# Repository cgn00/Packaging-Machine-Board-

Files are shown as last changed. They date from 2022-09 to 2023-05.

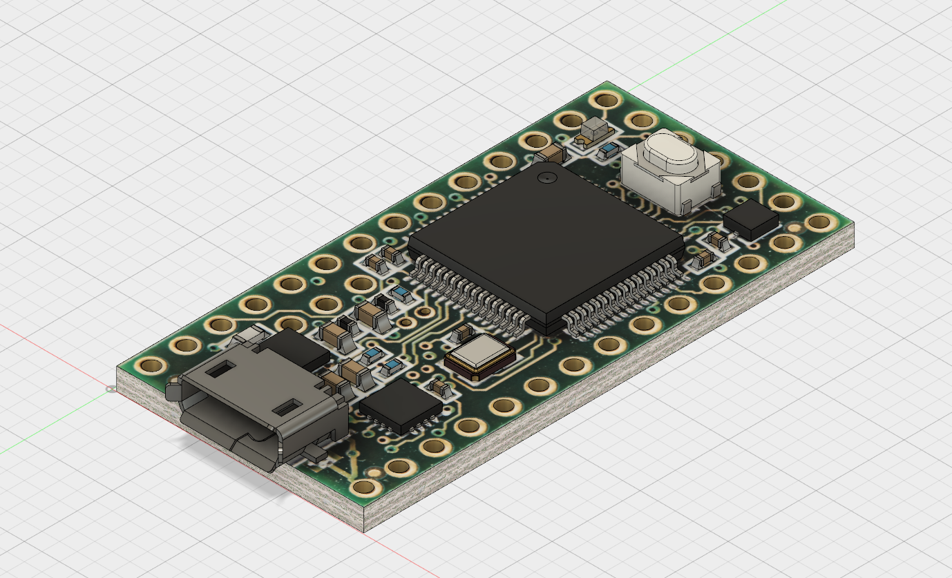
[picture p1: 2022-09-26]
librarys/teensy-3-2-2.snapshot.4/Teensy_3_1 v13.png

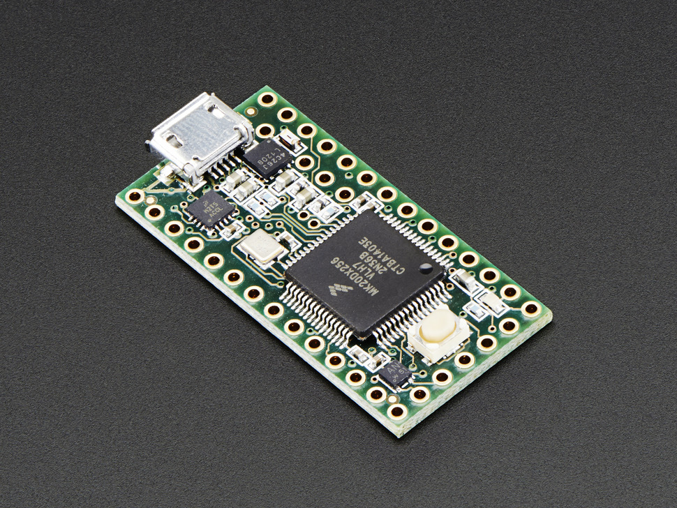
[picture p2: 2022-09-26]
librarys/adafruit-teensy-3-2-header-1.snapshot.2/2756-00.jpg

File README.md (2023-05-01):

# Packaging Machine Controller Board Design

This repository contains the design of a controller board for a packaging machine based on the Teensy 3.5 microcontroller. The controller board allows for control of the motors, sensors, and actuators necessary for the packaging process.

## Installation

To use this controller board, the KiCAD circuit design software is required. Clone this repository and open the .pro file in KiCAD.

## Usage

The controller board is designed to be used in a packaging machine. The pins are labeled and can be easily connected to the corresponding motors, sensors, and actuators.

The firmware necessary for the operation of the packaging machine can be loaded onto the Teensy 3.5 microcontroller using the Arduino development software.

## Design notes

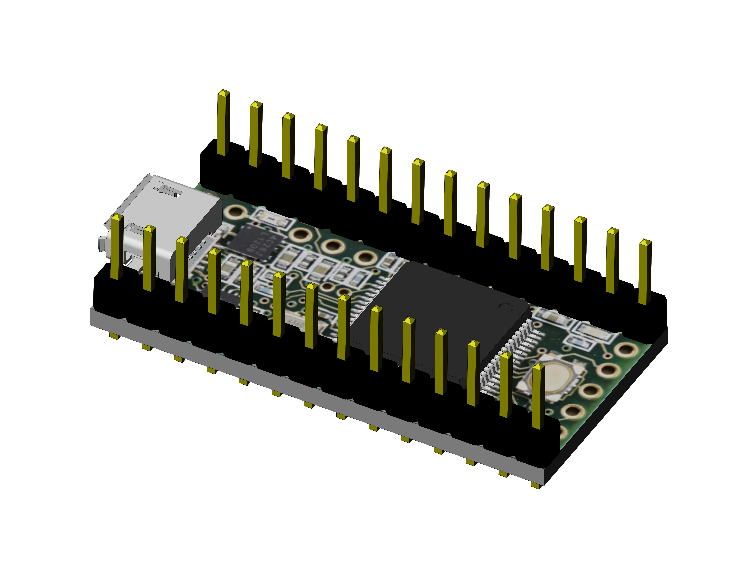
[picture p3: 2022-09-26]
librarys/adafruit-teensy-3-2-header-1.snapshot.2/Teensy 3.2 + header.JPG

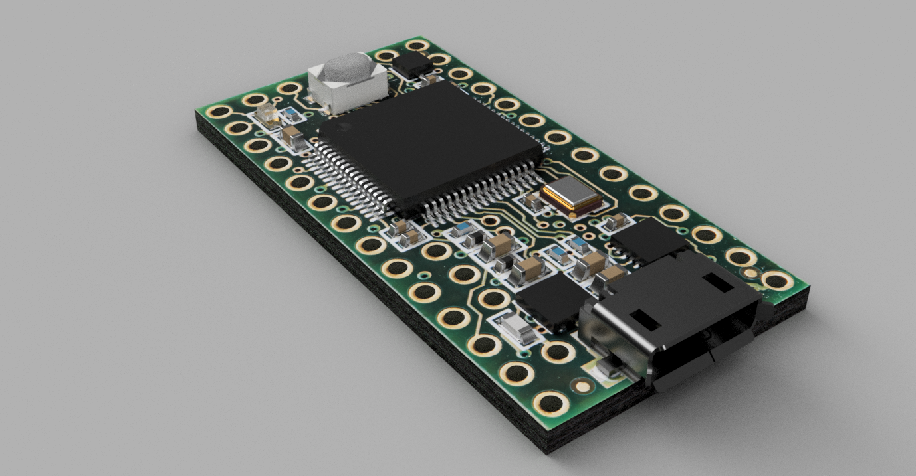
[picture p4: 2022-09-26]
librarys/teensy-3-2-2.snapshot.4/Renderings/Teensy_3_1 v12.png

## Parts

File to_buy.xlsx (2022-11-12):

Reference | Value | Footprint | Dadasheet |  | Qty | Link
BT1 | Battery_Cell | BatteryHolder_Keystone_103_1x20mm_new | ~ |  | 1 | https://lcsc.com/product-detail/Battery-Holders-Clips-Contacts_CR2032battery_C70376.html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
> C1-C14, C23, C24, C26 | 0.1uF | Capacitor_SMD:C_1206_3216Metric | ~ |  | 17 | https://lcsc.com/product-detail/Multilayer-Ceramic-Capacitors-MLCC-SMD-SMT_FH-Guangdong-Fenghua-Advanced-Tech-1206B104K500NT_C110253.html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
C15 | 10uF | Capacitor_SMD:C_0805_2012Metric_Pad1.18x1.45mm_HandSolder | ~ |  | 1 | https://lcsc.com/product-detail/Multilayer-Ceramic-Capacitors-MLCC-SMD-SMT_Murata-Electronics-GRM21BB31A106KE18L_C162316.html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
C16 | 0.1uF | Capacitor_SMD:C_0603_1608Metric_Pad1.08x0.95mm_HandSolder | ~ |  | 1 | https://lcsc.com/product-detail/Multilayer-Ceramic-Capacitors-MLCC-SMD-SMT_CT41G-0603-2X1-50V-0-1mF-K-N_C125205.html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
> C17, C18 | 18pF | Capacitor_SMD:C_0603_1608Metric | ~ |  | 2 | https://lcsc.com/product-detail/Multilayer-Ceramic-Capacitors-MLCC-SMD-SMT_Murata-Electronics-GRM1882C1H180JA01D_C415402.html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
> C19, C20 | 0.1uF | Capacitor_SMD:C_0805_2012Metric_Pad1.18x1.45mm_HandSolder | ~ |  | 2 | https://lcsc.com/product-detail/Multilayer-Ceramic-Capacitors-MLCC-SMD-SMT_CCTC-TCC0805X7R104K500DT_C282732.html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
> C21, C27 | 220uF | Capacitor_SMD:CP_Elec_6.3x7.7 | ~ |  | 2 | https://lcsc.com/product-detail/Aluminum-Electrolytic-Capacitors-Leaded_CX-Dongguan-Chengxing-Elec-220uF-25V-high-frequency_C114911.html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
C22 | 0.1uF | Capacitor_SMD:C_0805_2012Metric | ~ |  | 1 | https://lcsc.com/product-detail/Multilayer-Ceramic-Capacitors-MLCC-SMD-SMT_CCTC-TCC0805X7R104K500DT_C282732.html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
C25 | 470uF | Capacitor_THT:C_Radial_D8.0mm_H11.5mm_P3.50mm | ~ |  | 1 | https://lcsc.com/product-detail/Aluminum-Electrolytic-Capacitors-Leaded_CX-Dongguan-Chengxing-Elec-470uF-100V-16-25_C72551.html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
> D1-D22, D29 | GREEN-LED | LED_SMD:LED_1206_3216Metric_Castellated | ~ |  | 23 | https://lcsc.com/product-detail/Others_Everlight-Elec-15-21SDRC-S530-A2-TR8_C264387.html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
> D23-D28, D30 | LED | LED_SMD:LED_1206_3216Metric_Castellated | ~ |  | 7 | https://lcsc.com/product-detail/Others_Everlight-Elec-15-21SDRC-S530-A2-TR8_C264387.html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
D31 | D_Schottky | Diode_SMD:D_SMA_Handsoldering | ~ |  | 1 | https://lcsc.com/search?q=SS14E-TP
> D32, D33 | 1N47xxA | Diode_THT:D_DO-41_SOD81_P10.16mm_Horizontal | https://www.vishay.com/docs/85816/1n4728a.pdf |  | 2 | https://lcsc.com/product-detail/Zener-Diodes_ON-Semiconductor-ON-1N4733A_C140851.html?from_code=PL20191220BSDR
F1 | Fuse | Fuse:Fuse_2920_7451Metric_Castellated | ~ |  | 1 | https://lcsc.com/product-detail/Resettable-Fuses_span-style-background-color-ff0-TECHFUSE-span-SMD400L-24V_C2937113.html
> J1, J11 | Screw_Terminal_01x02 | TerminalBlock_Altech:Altech_AK300_1x02_P5.00mm_45-Degree | ~ |  | 2 | https://lcsc.com/product-detail/Screw-terminal_DIBO-DB128V-5-0-2P-GN-S_C395860.html
> J2, J7, J8 | Screw_Terminal_01x06 | TerminalBlock_Altech:Altech_AK300_1x06_P5.00mm_45-Degree | ~ |  | 3 | https://lcsc.com/product-detail/Screw-terminal_span-style-background-color-ff0-DIBO-span-DB128V-5-0-3P-GN-S_C484209.html |  |  | NOTA: el link es un TB de 3 pines, para hacer 1 de 6 serían montar 2, 2*3=6
J3 | Screw_Terminal_01x10 | TerminalBlock_Altech:Altech_AK300_1x10_P5.00mm_45-Degree | ~ |  | 1 | NOTA: montar dos Terminal Block(TB) de 3 y dos de 2
> J4, J5 | Screw_Terminal_01x05 | TerminalBlock_Altech:Altech_AK300_1x05_P5.00mm_45-Degree | ~ |  | 2 |  |  | NOTA: Montar 1TB de 3 y 1TB de 2
J6 | RJ45_LED | Connector_RJ:RJ45_Hanrun_HR911105A | ~ |  | 1 | https://lcsc.com/product-detail/Ethernet-Connectors-Modular-Connectors-RJ45-RJ11_HANRUN-Zhongshan-HanRun-Elec-HR911105A_C12074.html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
> J9, J10 | Screw_Terminal_01x06 | Connector_PinSocket_2.54mm:PinSocket_1x06_P2.54mm_Vertical | ~ |  | 2 | https://www.lcsc.com/product-detail/Female-Headers_ZHOURI-2-54-1-40_C2977610.html
J12 | Ethernet | Connector_PinHeader_2.54mm:PinHeader_1x06_P2.54mm_Vertical | ~ |  | 1 | https://lcsc.com/product-detail/Wire-To-Board-Wire-To-Wire-Connector_TE-Connectivity_6-146276-0_TE-Connectivity-6-146276-0_C306214.html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
J13 | Screw_Terminal_01x04 | TerminalBlock_Altech:Altech_AK300_1x04_P5.00mm_45-Degree | ~ |  | 1 |  |  | NOTA: Montar 2 TB de 2
J14 | CAN | Connector_PinHeader_2.54mm:PinHeader_1x04_P2.54mm_Vertical | ~ |  | 1 | https://lcsc.com/product-detail/Wire-To-Board-Wire-To-Wire-Connector_TE-Connectivity_6-146276-0_TE-Connectivity-6-146276-0_C306214.html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
J15 | SERIAL_1 | Connector_PinHeader_2.54mm:PinHeader_1x04_P2.54mm_Vertical | ~ |  | 1
J16 | I2C0 | Connector_PinHeader_2.54mm:PinHeader_1x04_P2.54mm_Vertical | ~ |  | 1
J17 | I2C1 | Connector_PinHeader_2.54mm:PinHeader_1x04_P2.54mm_Vertical | ~ |  | 1
J19 | SERIAL_5 | Connector_PinHeader_2.54mm:PinHeader_1x04_P2.54mm_Vertical | ~ |  | 1
> J18, J20-J25 | Screw_Terminal_01x01 | Connector_PinHeader_2.54mm:PinHeader_1x01_P2.54mm_Vertical | ~ |  | 7
> K1-K8 | UMS05-1A80-75L | relay_HF49FD_024_1H11:Relay_SPST_TE_PCN-1xxD3MHZ | https://standexelectronics.com/de/produkte/ums-reed-relais/ |  | 8 | https://lcsc.com/product-detail/Relays_HF-Xiamen-Hongfa-Electroacoustic-HF49FD-024-1H11_C33824.html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
L1 | 0.1uH | Inductor_SMD:L_0805_2012Metric_Pad1.15x1.40mm_HandSolder | ~ |  | 1 | https://lcsc.com/product-detail/Inductors-SMD_FH-Guangdong-Fenghua-Advanced-Tech-CMP201209UD1R0MT_C401475.html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
> Q1-Q7 | IRG4PF50W | Package_TO_SOT_SMD:TO-252-2 | http://www.irf.com/product-info/datasheets/data/irg4pf50w.pdf |  | 7 | https://lcsc.com/product-detail/IGBTs_Alpha-Omega-Semicon-AOD5B60D_C176751.html?from_code=PL20191220BSDR
> R1-R14, R81 | 20k | Resistor_SMD:R_1206_3216Metric_Pad1.30x1.75mm_HandSolder | ~ |  | 15 | https://lcsc.com/product-detail/Chip-Resistor-Surface-Mount_20KR-203-5_C102303.html?from_code=PL20191220BSDR
> R15-R28, R41-R43, R82 | 10K | Resistor_SMD:R_0603_1608Metric | ~ |  | 18 | https://lcsc.com/product-detail/Others_ResistorToday-ETCR0603F10K0K9_C365375.html?from_code=PL20191220BSDR
> R29, R30 | 10k | Resistor_SMD:R_0603_1608Metric | ~ |  | 2 | https://lcsc.com/product-detail/Others_ResistorToday-ETCR0603F10K0K9_C365375.html?from_code=PL20191220BSDR
> R31, R50 | 1.2k | Resistor_SMD:R_1206_3216Metric_Pad1.30x1.75mm_HandSolder | ~ |  | 2 | https://lcsc.com/product-detail/Chip-span-style-background-color-ff0-Resistor-span-Surface-Mount_TyoHM-RMC12061-2K1-N_C269579.html
> R32-R39 | 4.7k | Resistor_SMD:R_1206_3216Metric_Pad1.30x1.75mm_HandSolder | ~ |  | 8 | https://lcsc.com/product-detail/Chip-Resistor-Surface-Mount_470R-4700-1_C104814.html?from_code=PL20191220BSDR
R40 | 2.7k | Resistor_SMD:R_0603_1608Metric | ~ |  | 1 | https://lcsc.com/product-detail/Chip-Resistor-Surface-Mount_Resistor-Today-AECR0603F2K70K9_C328353.html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
> R44, R45 | 470 | Resistor_SMD:R_0603_1608Metric | ~ |  | 2 | https://lcsc.com/product-detail/Chip-Resistor-Surface-Mount_RALEC-RAT034700FTP_C304484.html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
> R46-R49 | 49.9 | Resistor_SMD:R_0805_2012Metric_Pad1.20x1.40mm_HandSolder | ~ |  | 4 | https://lcsc.com/product-detail/Chip-Resistor-Surface-Mount_TyoHM-RMC080549-91-N_C269747.html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
> R51, R56-R60, R83 | 1k | Resistor_SMD:R_0603_1608Metric | ~ |  | 7 | https://lcsc.com/product-detail/Chip-Resistor-Surface-Mount_TyoHM-RMC06031K5-N_C269685.html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
> R52, R61-R65, R84 | 390 | Resistor_SMD:R_0603_1608Metric_Pad0.98x0.95mm_HandSolder | ~ |  | 7 | https://lcsc.com/product-detail/Chip-span-style-background-color-ff0-Resistor-span-Surface-Mount_VO-SCR0603J390R_C3017746.html
> R53, R54, R66, R67, R69, R70, R72, R73, R75, R76, R78, R79, R85, R86 | 1k | Resistor_SMD:R_0805_2012Metric_Pad1.20x1.40mm_HandSolder | ~ |  | 14 | https://lcsc.com/product-detail/Chip-Resistor-Surface-Mount_Resistor-Today-AECR0805F1K00K9_C328385.html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
> R55, R68, R71, R74, R77, R80, R87 | 10k | Resistor_SMD:R_0805_2012Metric_Pad1.20x1.40mm_HandSolder | ~ |  | 7 | https://lcsc.com/product-detail/Chip-Resistor-Surface-Mount_SEI-Stackpole-Elec-RMCF0805FT10K0_C237755.html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
> R88, R89, R91, R92 | 10k | Resistor_SMD:R_1206_3216Metric | ~ |  | 4 | https://lcsc.com/product-detail/Chip-Resistor-Surface-Mount_Resistor-Today-AECR1206F10K0K9_C328409.html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
> SW1-SW3, SW5 | SW_DIP_x01 | Connector_PinHeader_2.54mm:PinHeader_1x02_P2.54mm_Vertical | ~ |  | 4 | https://lcsc.com/product-detail/Wire-To-Board-Wire-To-Wire-Connector_TE-Connectivity_6-146276-0_TE-Connectivity-6-146276-0_C306214.html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
SW4 | Prog | Connector_PinHeader_2.54mm:PinHeader_1x02_P2.54mm_Vertical | ~ |  | 1
SW6 | SW_DIP_x01 | Button_Switch_THT:SW_DIP_SPSTx01_Slide_9.78x4.72mm_W7.62mm_P2.54mm | ~ |  | 1
> U9, U10, U28-U33, U35 | TLP127 | Package_SO:MFSOP6-4_4.4x3.6mm_P1.27mm | https://toshiba.semicon-storage.com/info/docget.jsp?did=16902&prodName=TLP127 |  | 9 | https://lcsc.com/product-detail/Optocouplers_TOSHIBA_TLP127-TPL-U-F_TOSHIBA-TLP127-TPL-U-F_C5001.html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
> U1-U8, U11-U14, U34 | tlp127 | Package_SO:MFSOP6-4_4.4x3.6mm_P1.27mm | https://toshiba.semicon-storage.com/info/docget.jsp?did=16902&prodName=TLP127 |  | 13
> U15, U16 | 74HC14 |  | http://www.ti.com/lit/gpn/sn74HC14 |  | 2 | https://lcsc.com/product-detail/74-Series_Nexperia_74HC14D-653_74HC14D-653_C5605.html?from_code=PL20191220BSDR
> U15-U17 | 74HC14 | Package_SO:SOIC-14_3.9x8.7mm_P1.27mm | http://www.ti.com/lit/gpn/sn74HC14 |  | 3
> U18, U20 | 74HC245 | Package_SO:SO-20_12.8x7.5mm_P1.27mm | http://www.ti.com/lit/gpn/sn74HC245 |  | 2 | https://lcsc.com/product-detail/74-Series_NXP_74HC245D-653_74HC245D_C5625.html?from_code=PL20191220BSDR
U19 | Teensy3.5_All_Pins | teensy:Teensy35_36_MODIFY | https://www.pjrc.com/teensy/card8a_rev2.pdf | https://www.pjrc.com/teensy/pinout.html | 1
U21 | ULN2803A | Package_SO:SOP-18_7x12.5mm_P1.27mm | http://www.ti.com/lit/ds/symlink/uln2803a.pdf |  | 1 | https://lcsc.com/product-detail/Darlington-transistor-array-driver_Sinotech-Mixic-Elec-ULN2803A_C107219.html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
> U22, U23, U26, U27 | 74AHCT125 | Package_SO:SOIC-14_3.9x8.7mm_P1.27mm |  |  | 4 | https://www.mouser.com/ProductDetail/Texas-Instruments/SN74AHCT125QDRQ1?qs=zhgwDAIOVxtE5BLiD9k5oQ%3D%3D
U24 | ENC28J60x-SS | Package_SO:SSOP-28_5.3x10.2mm_P0.65mm | http://ww1.microchip.com/downloads/en/devicedoc/39662e.pdf |  | 1 | https://lcsc.com/product-detail/Ethernet-ICs_Microchip-Tech-ENC28J60-I-SS_C411626.html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
U25 | LD1117S33TR_SOT223 | Package_TO_SOT_SMD:SOT-223-3_TabPin2 | http://www.st.com/st-web-ui/static/active/en/resource/technical/document/datasheet/CD00000544.pdf |  | 1 | https://lcsc.com/product-detail/Others_KEXIN-AMS1117-3-3_C369933.html?from_code=PL20191220BSDR
U36 | LM7810_TO220 | Package_TO_SOT_THT:TO-220-3_Vertical | https://www.onsemi.cn/PowerSolutions/document/MC7800-D.PDF |  | 1 | https://lcsc.com/product-detail/Linear-Voltage-Regulators_UTC-Unisonic-Tech-LM7810L-TA3-T_C95077.html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
Y1 | 25Mhz | Crystal:Crystal_HC49-4H_Vertical | ~ |  | 1 | https://lcsc.com/product-detail/DIP-Crystal-Resonators_Suzhou-Liming-Elec-49S-25-000-20-20-20-A_C240913.html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
NOTA: | En el pin header Serial_1(J15) se conecta el módulo para la comunicación serial RS232 o RS485 con el HMI |  |  |  |  | RS232 | https://www.amazon.com/Ultra-Compact-RS232-Converter-Female/dp/B00OPTOKI0
 |  |  |  |  |  |  | https://www.google.com/url?psig=AOvVaw0IhrkeCjquqXJ8e-zahKvy&cd=vfe
 |  |  |  |  |  |  | https://protosupplies.com/product/max3232-ttl-to-rs-232-interface-module/
 |  |  |  |  |  | RS485: | https://protosupplies.com/product/scm-ttl-to-rs-485-interface-module/
 |  |  |  |  |  |  | https://www.google.com/url?rct=j&q=&esrc=s&cd=&cad=rja&uact=8

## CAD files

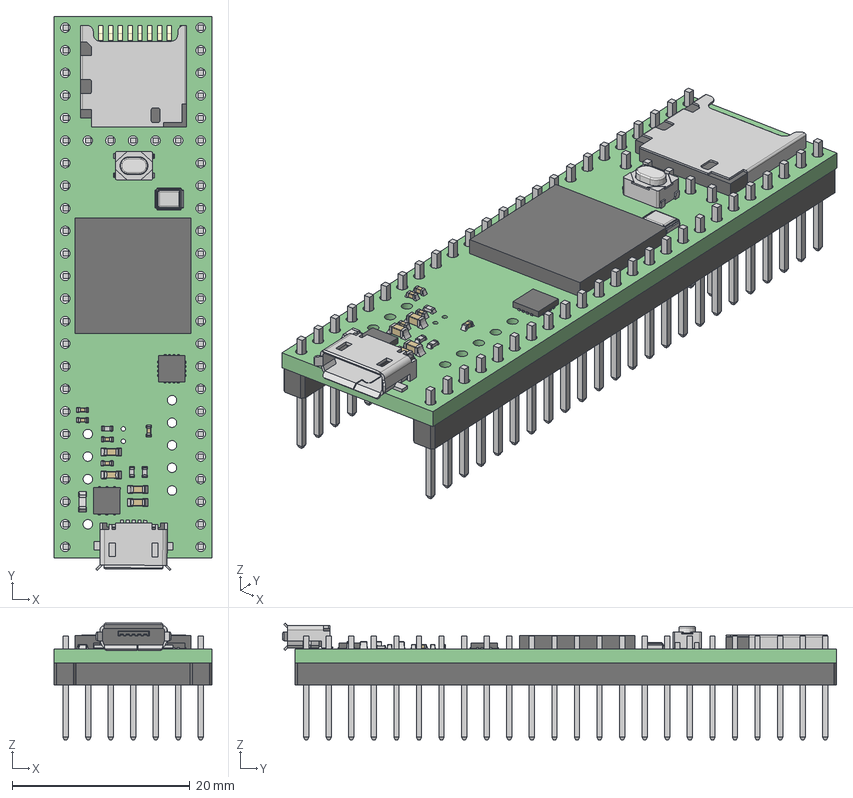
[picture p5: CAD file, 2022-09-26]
librarys/teensy.pretty-master/teensy.pretty-master/Teensy_3.5_3.6_Assembly.step
17.8 x 62.4 x 13.1 mm
micro_usb_plastic (1)
micro_usb_shell (1)
package
lead (1)
lead (2)
diode_0402 v1 x 4
cap0603_03 v3 x 5
cap0402 v2 (1) x 2
smt_led_0805 v2
cap0402 v2 x 5
resistor_0603 v3
Full Board
lead
Base
Case

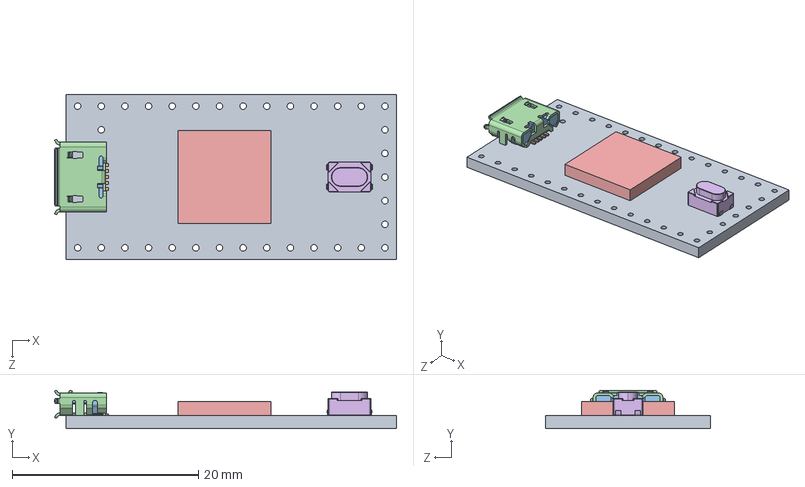
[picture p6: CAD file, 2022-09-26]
librarys/teensy.pretty-master/teensy.pretty-master/Teensy_4.0_Assembly.STEP
36.8 x 4.12 x 17.7 mm
Teensy_4.0_PCB
Micro USB-B Female 5Pin SMD
NXP iMXRT1062
SKRPACE010 v4

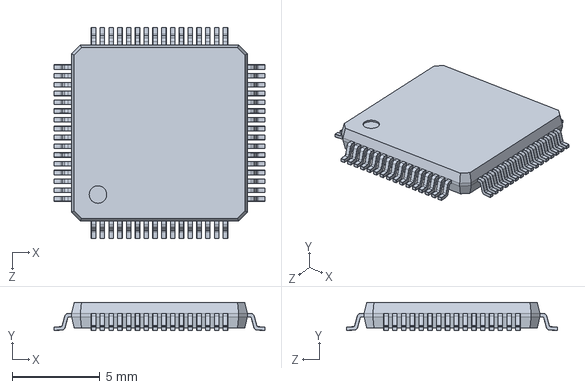
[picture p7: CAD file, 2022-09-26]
librarys/adafruit-teensy-3-2-header-1.snapshot.2/LQFP64_Grid_0.5_LQFP64_Koerper_2.SLDPRT
12.0 x 1.60 x 12.0 mm

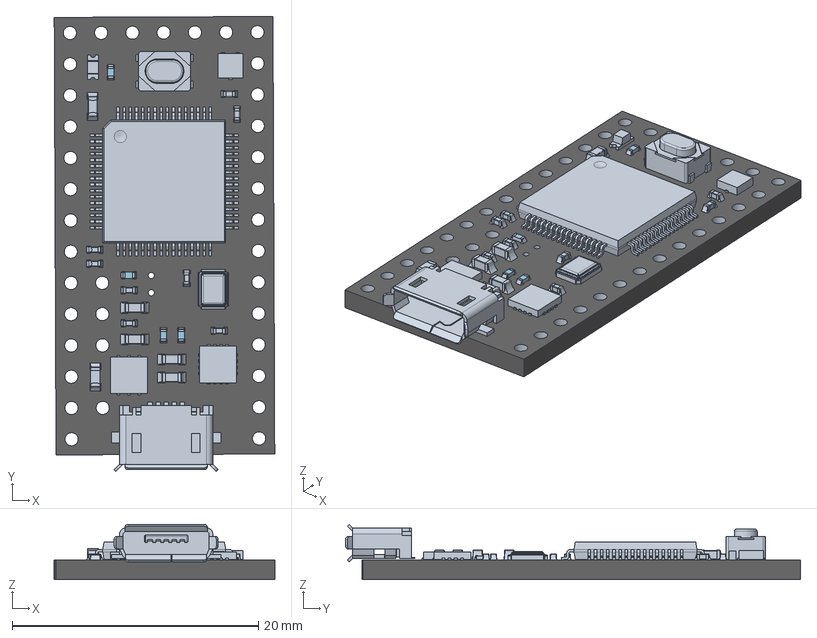
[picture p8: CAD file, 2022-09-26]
librarys/teensy-3-2-2.snapshot.4/Teensy_3_1.stp
17.9 x 37.0 x 4.49 mm
board
micro_usb_plastic (1)
micro_usb_shell (1)
lead
package (1)
lead (3) x 64
package
lead (1)
cap0402 v2 x 6
lead (2)
diode_0402 v1 x 4
cap0603_03 v3 x 5
cap0402 v2 (1) x 2
smt_led_0805 v2
resistor_0603 v3

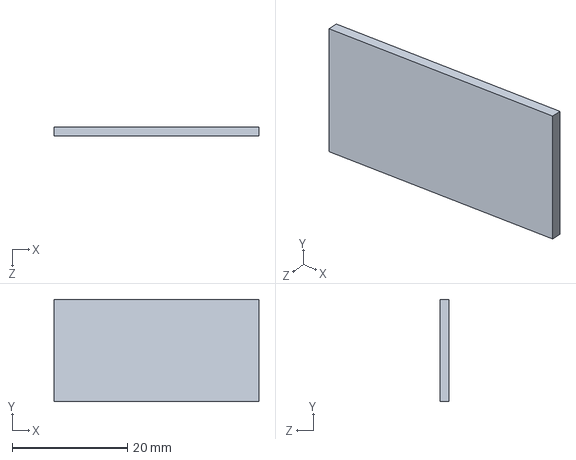
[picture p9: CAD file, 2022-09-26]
librarys/adafruit-teensy-3-2-header-1.snapshot.2/Teensy 3.2 + header.STEP
35.6 x 17.8 x 1.50 mm

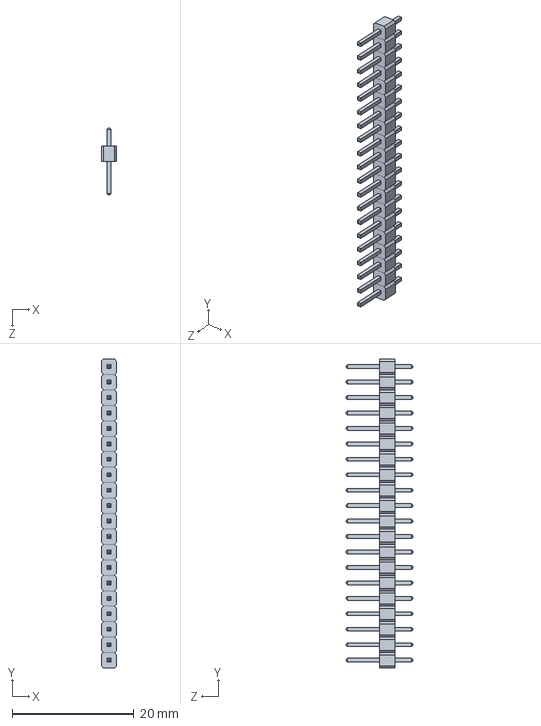
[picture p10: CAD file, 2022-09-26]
librarys/adafruit-teensy-3-2-header-1.snapshot.2/.100 Header.SLDPRT
2.54 x 50.8 x 11.1 mm

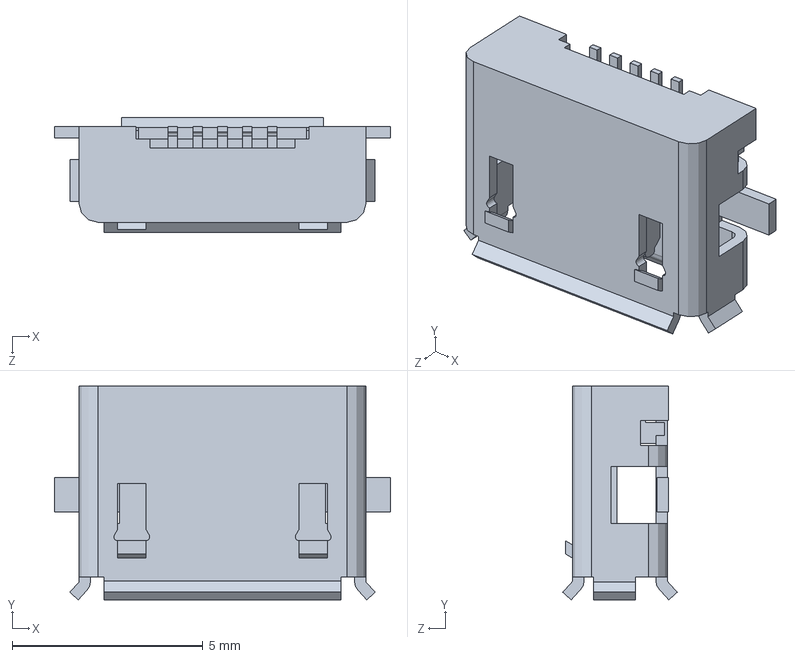
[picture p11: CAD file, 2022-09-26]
librarys/adafruit-teensy-3-2-header-1.snapshot.2/Hirose Micro USB Digikey PN H11635CT-ND.SLDASM
8.80 x 5.60 x 3.00 mm

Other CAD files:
librarys/adafruit-teensy-3-2-header-1.snapshot.2/Hirose Micro USB Digikey PN H11635CT-ND.SLDPRT
librarys/adafruit-teensy-3-2-header-1.snapshot.2/Teensy 3.2 + header.SLDASM
librarys/adafruit-teensy-3-2-header-1.snapshot.2/Teensy 3.2 + header.SLDPRT
librarys/teensy-3-2-2.snapshot.4/Teensy_3_1.igs
librarys/teensy-3-2-2.snapshot.4/Teensy_3_1.skp

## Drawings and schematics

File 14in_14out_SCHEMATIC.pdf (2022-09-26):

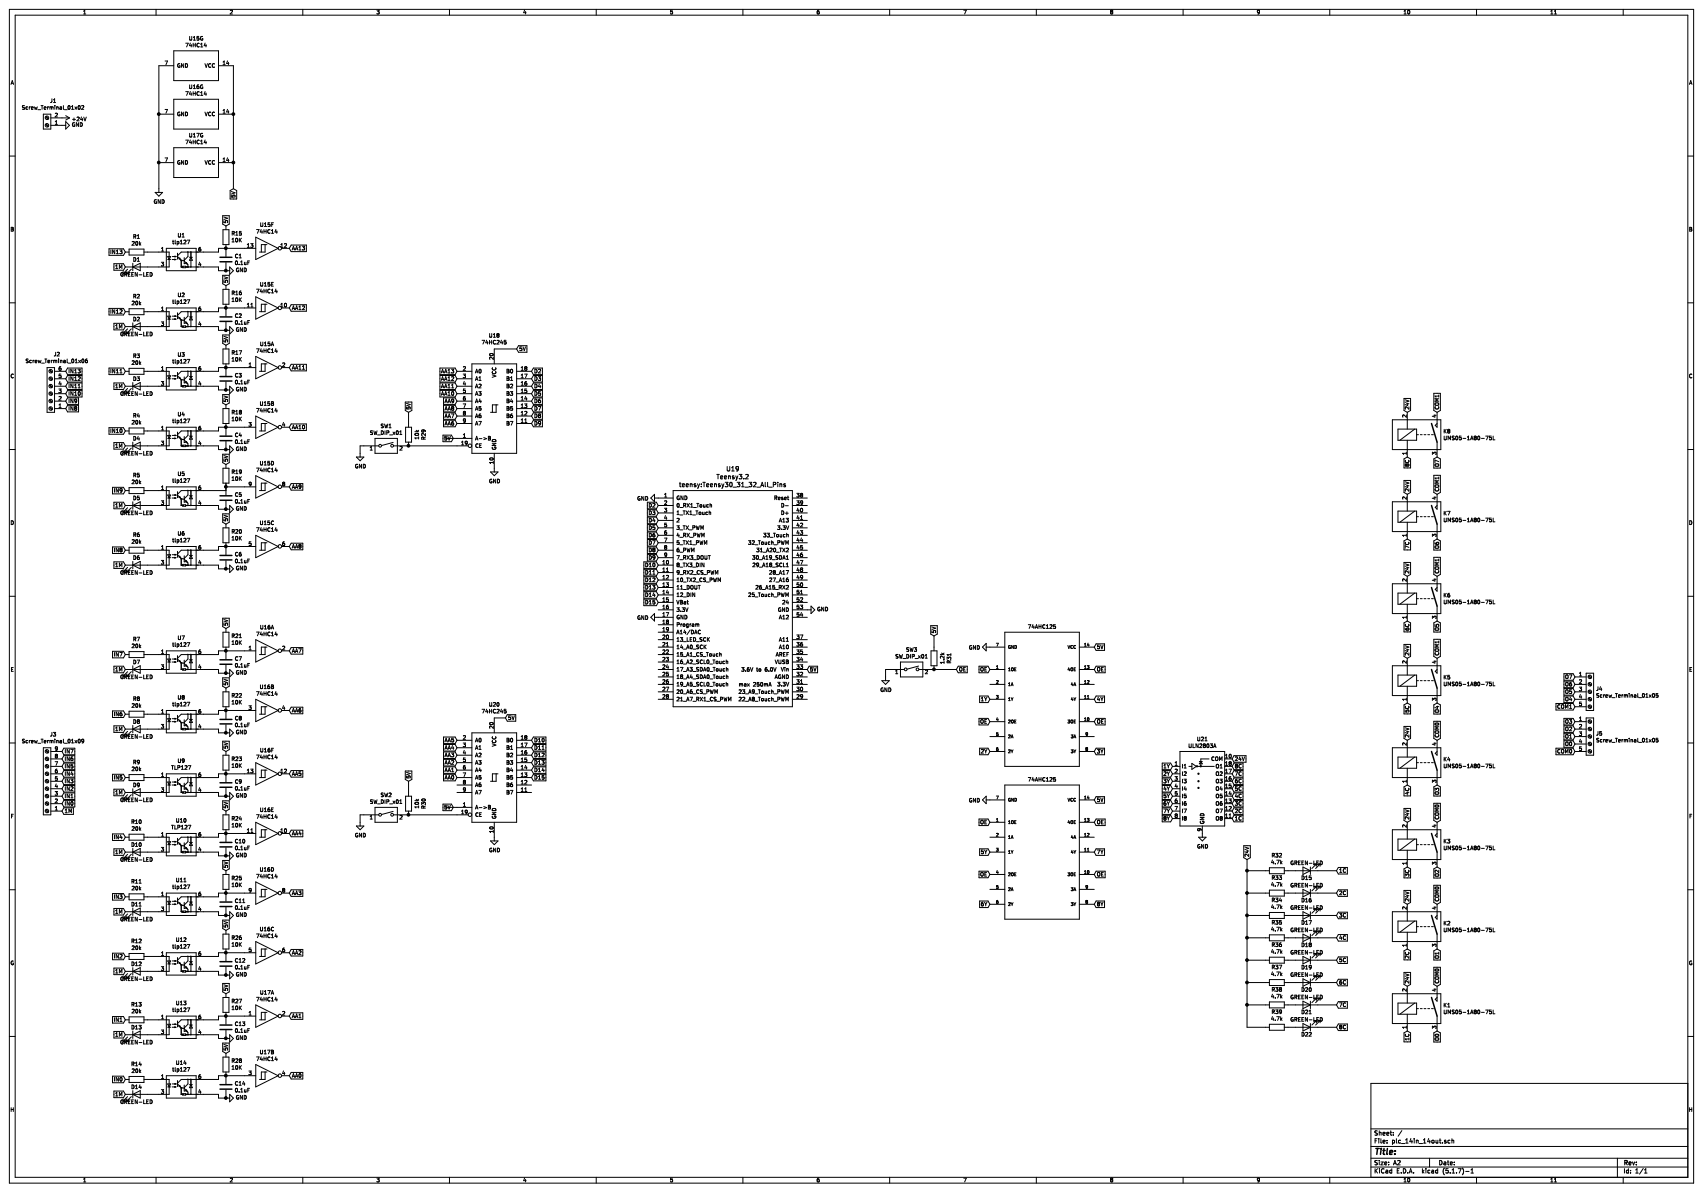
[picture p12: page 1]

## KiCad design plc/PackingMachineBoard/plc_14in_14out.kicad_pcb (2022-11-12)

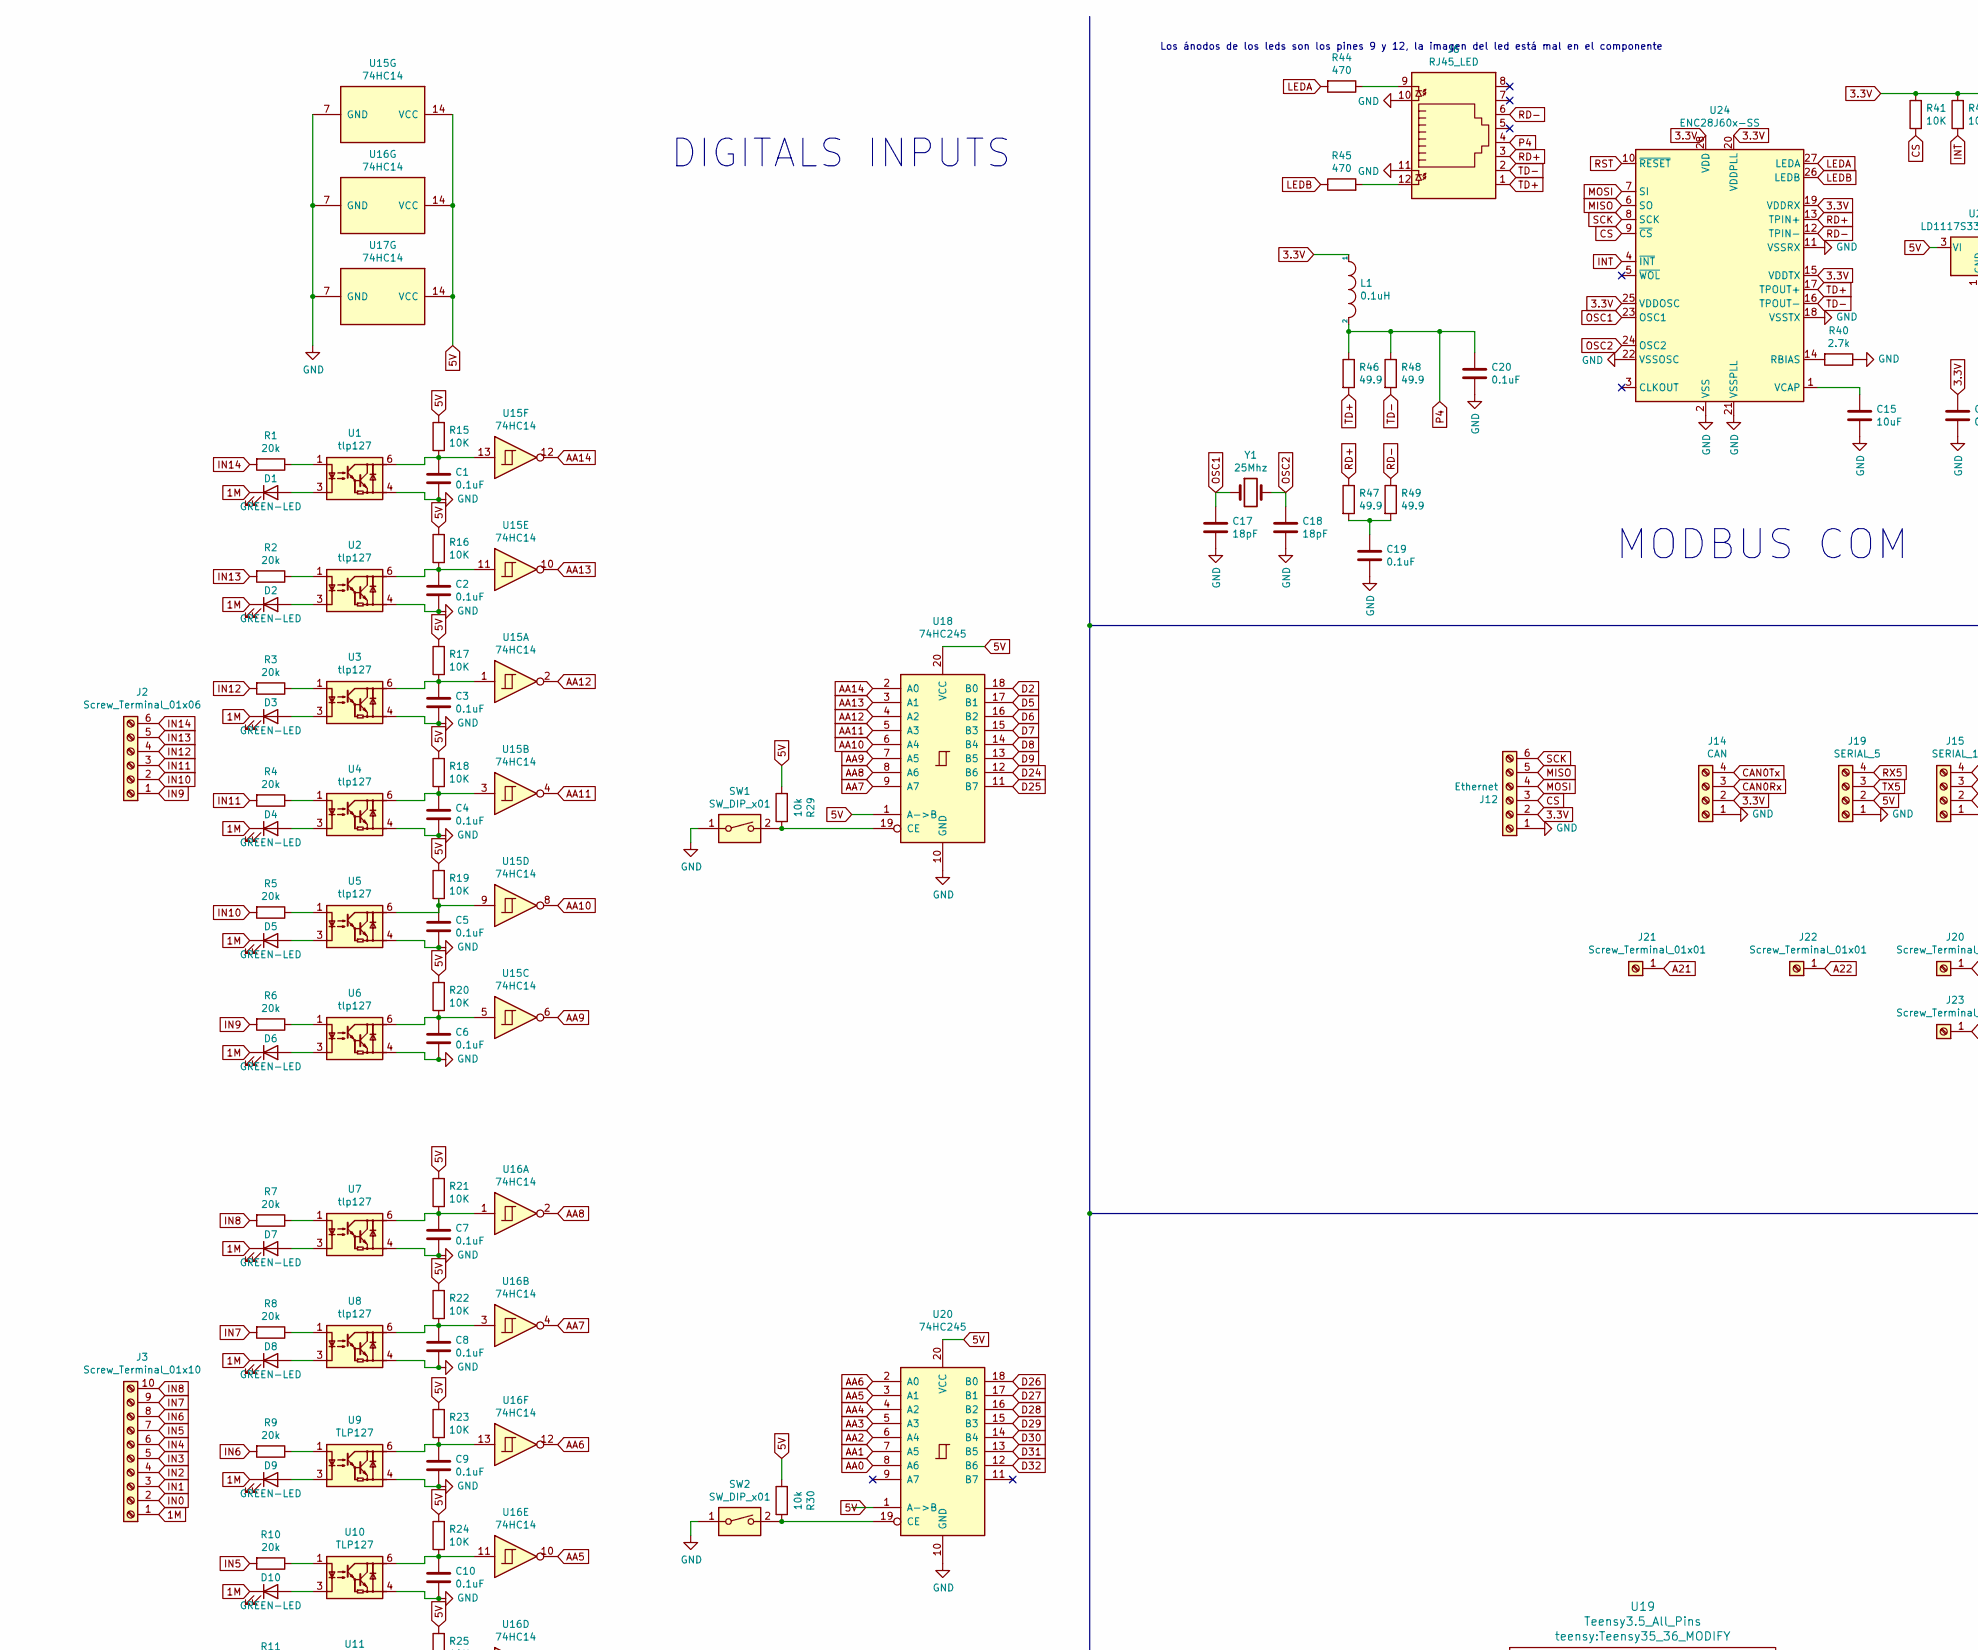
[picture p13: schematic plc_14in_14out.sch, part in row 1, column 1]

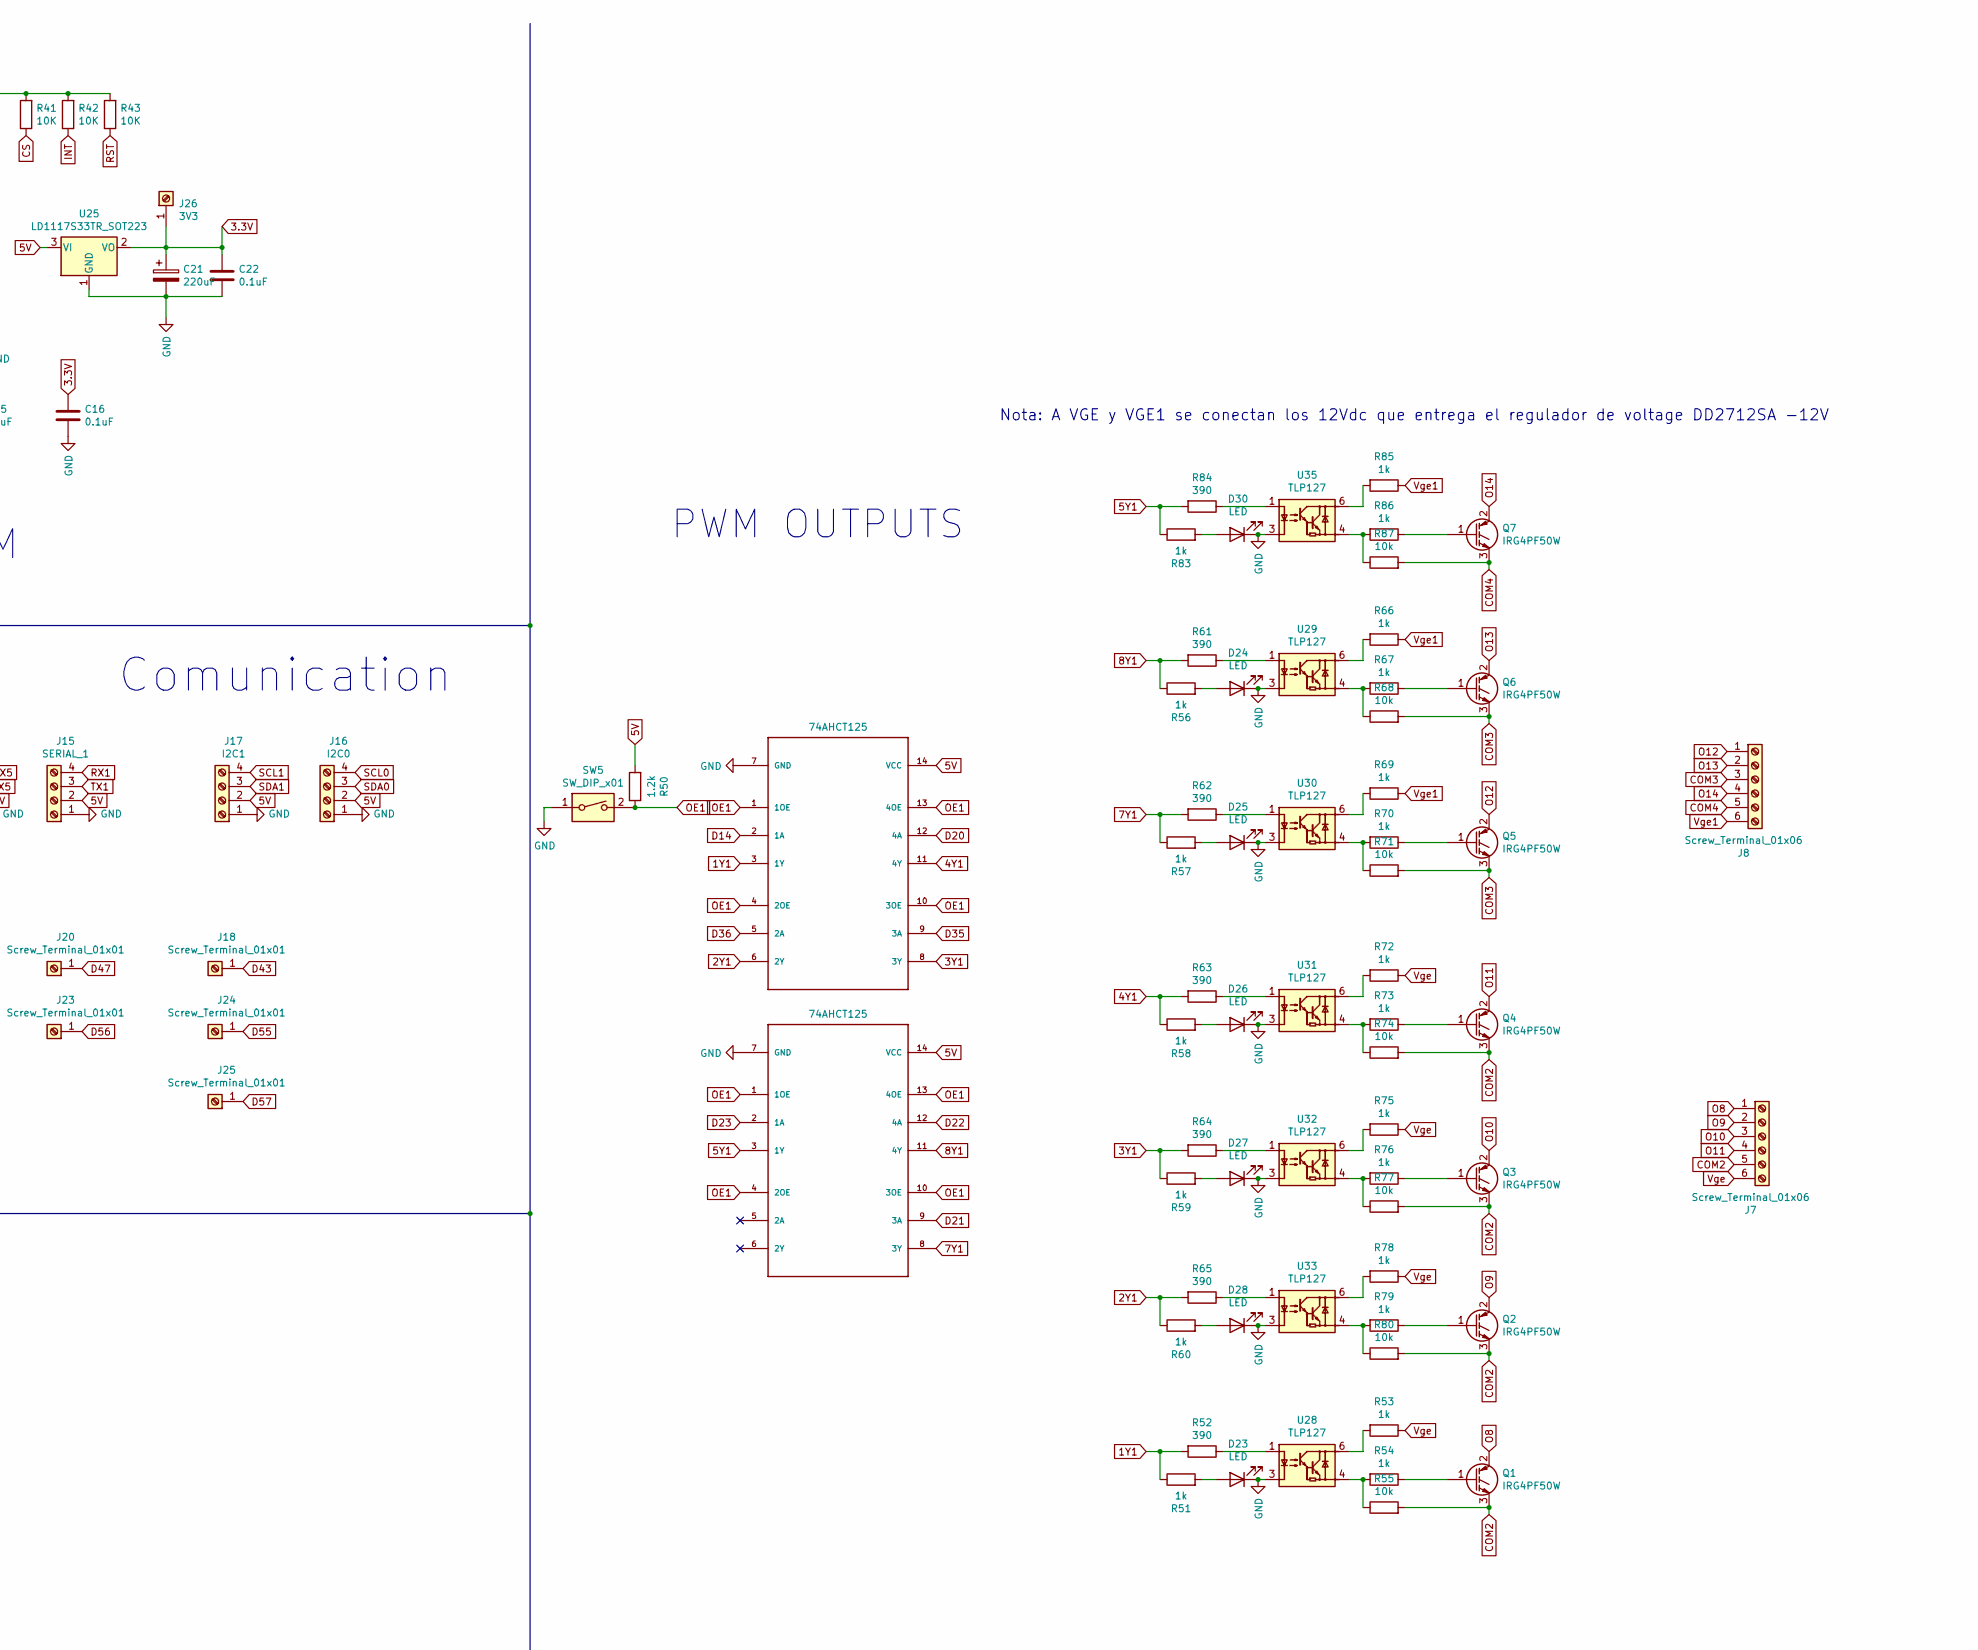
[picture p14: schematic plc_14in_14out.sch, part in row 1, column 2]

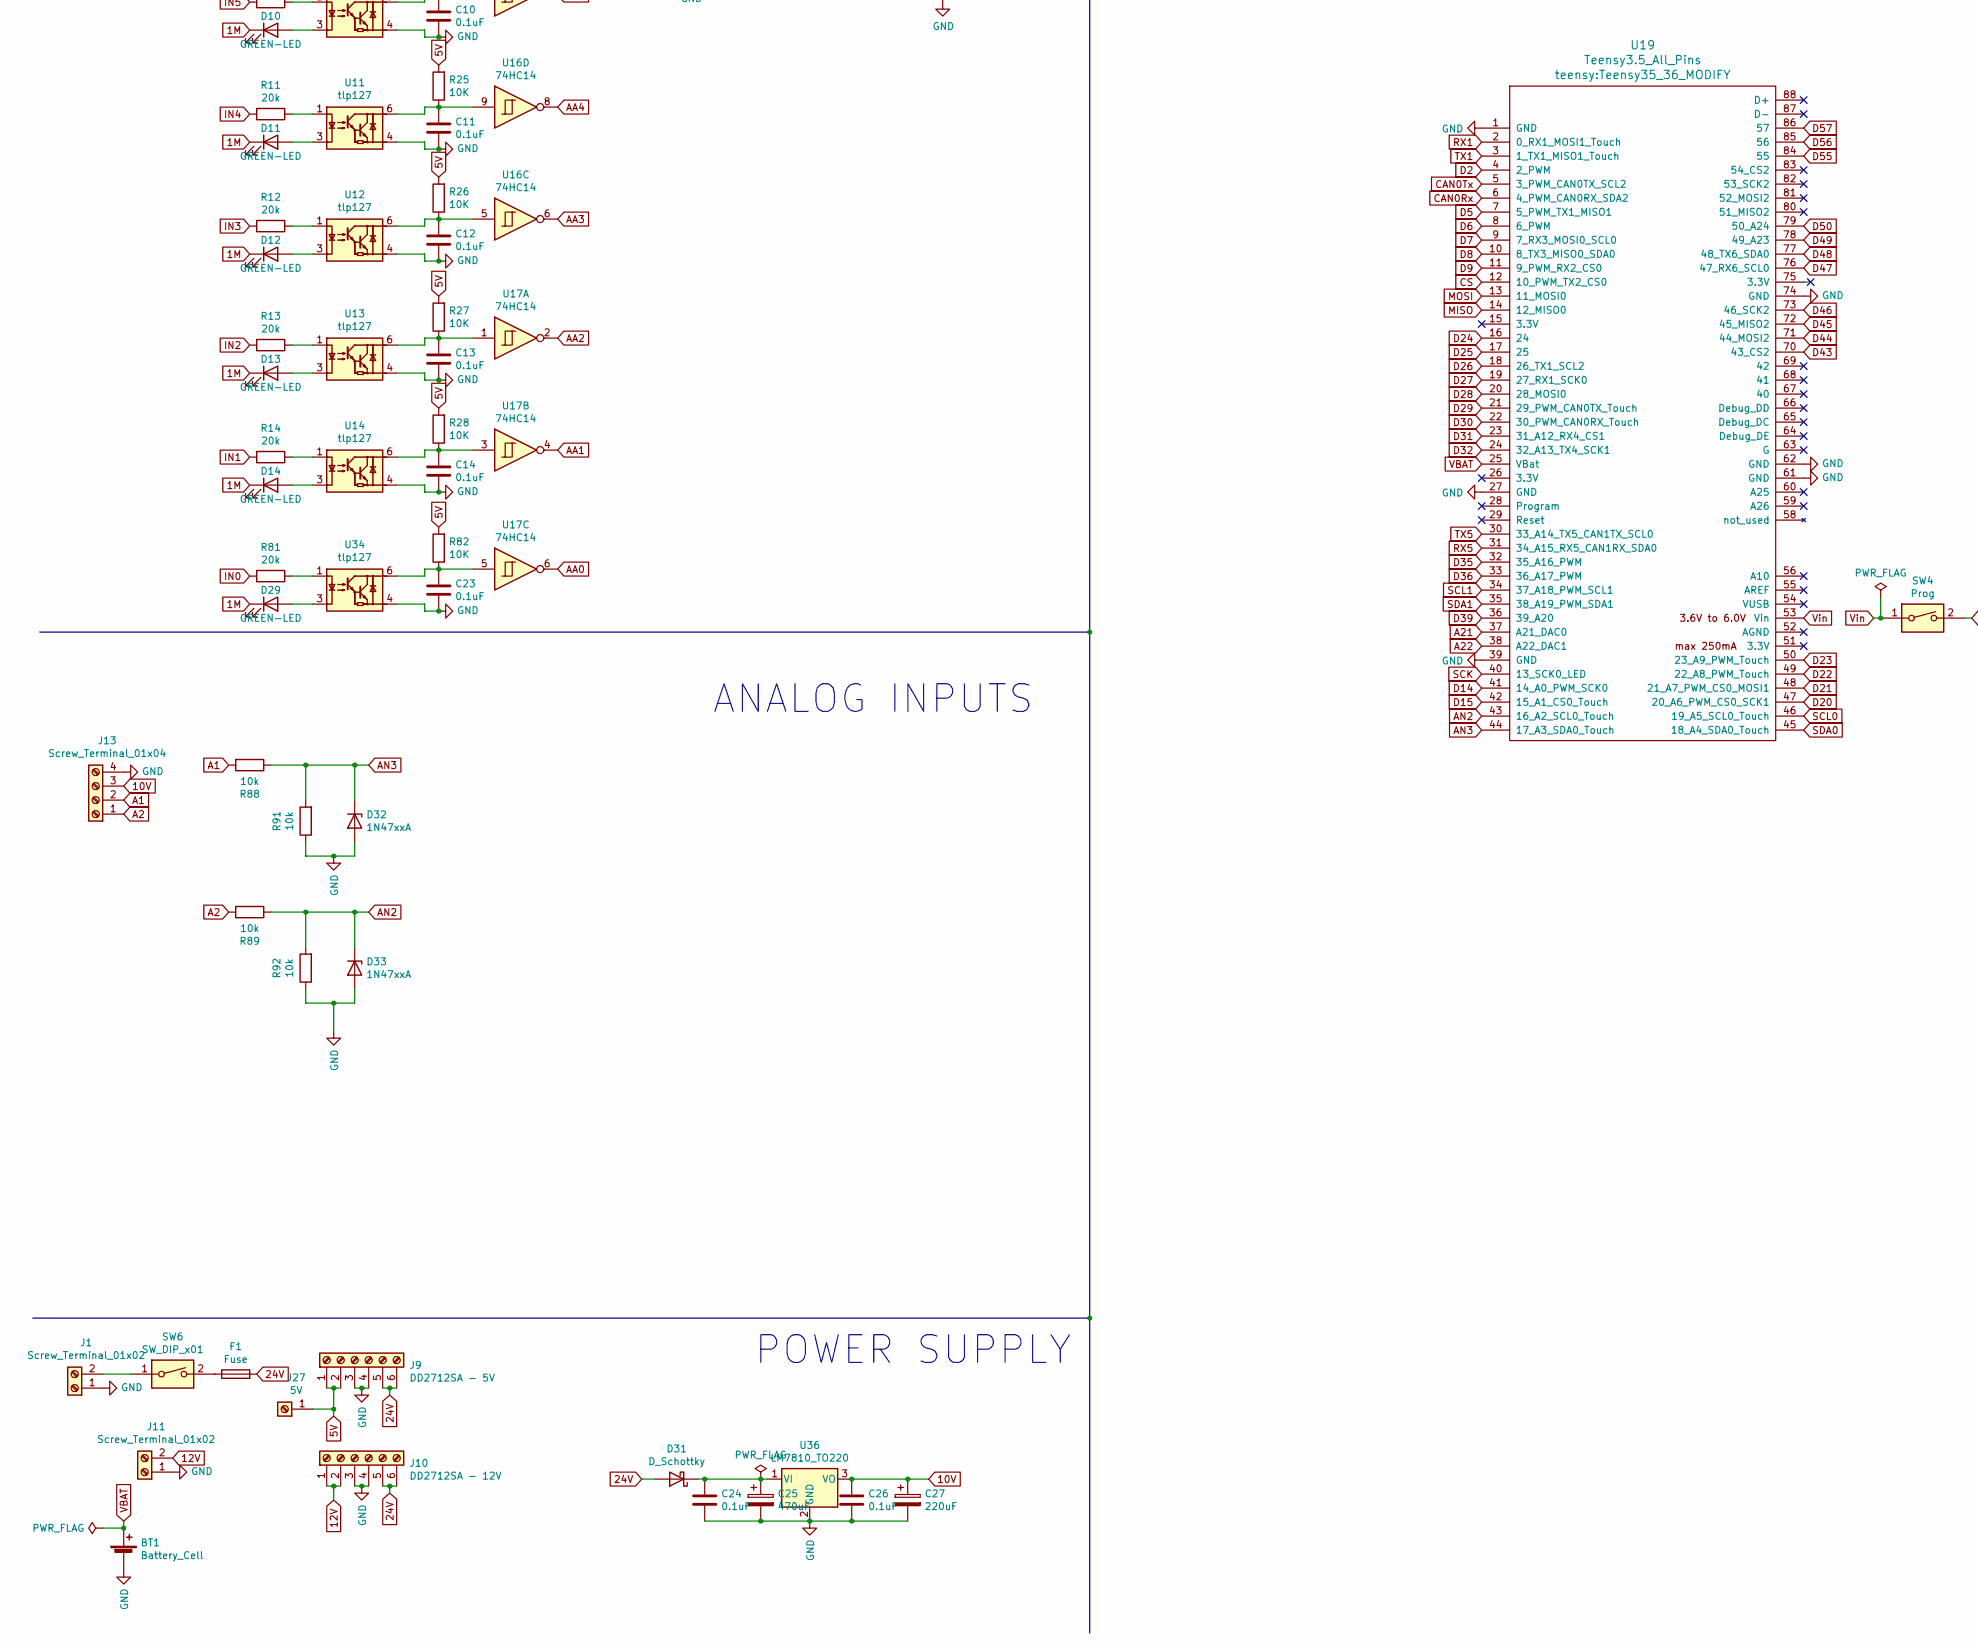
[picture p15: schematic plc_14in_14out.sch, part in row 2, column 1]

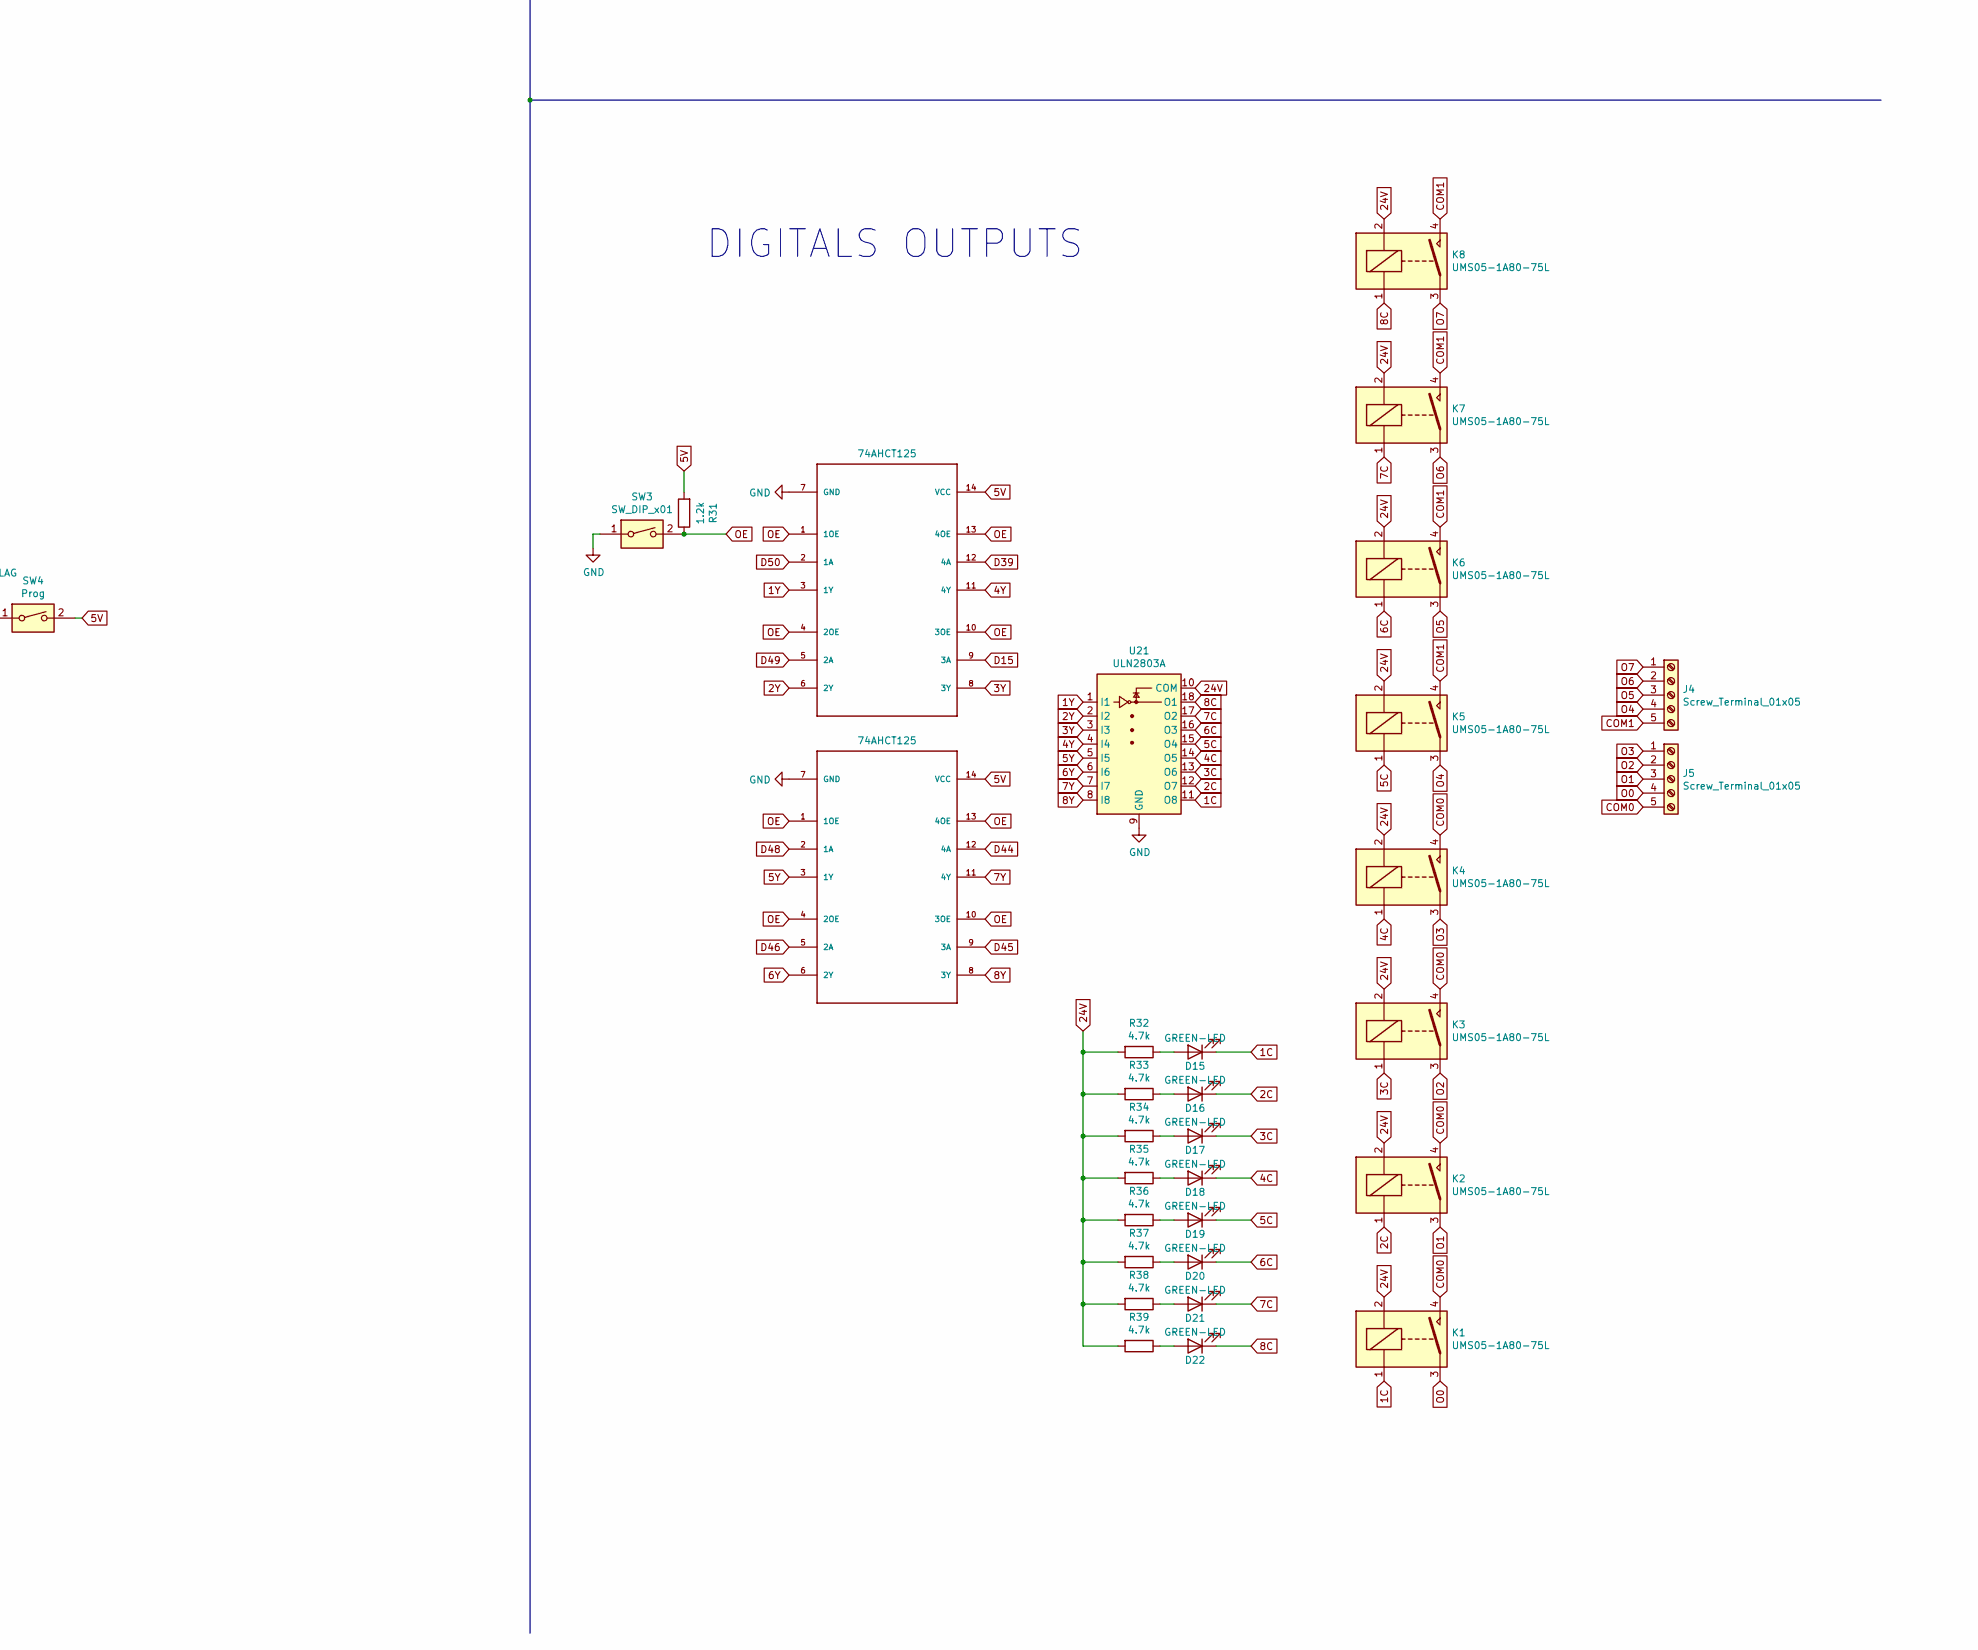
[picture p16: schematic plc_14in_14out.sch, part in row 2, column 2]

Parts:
BT1: Battery_Cell; BatteryHolder_Keystone_103_1x20mm_new
C1, C2, C3, C4, C5, C6, C7, C8, C9, C10, C11, C12, C13, C14, C23, C24, C26: 0.1uF; C_1206_3216Metric
C15: 10uF; C_0805_2012Metric_Pad1.18x1.45mm_HandSolder
C16: 0.1uF; C_0603_1608Metric_Pad1.08x0.95mm_HandSolder
C17, C18: 18pF; C_0603_1608Metric
C19, C20: 0.1uF; C_0805_2012Metric_Pad1.18x1.45mm_HandSolder
C21, C27: 220uF; CP_Elec_6.3x7.7
C22: 0.1uF; C_0805_2012Metric
C25: 470uF; C_Radial_D8.0mm_H11.5mm_P3.50mm
D1, D2, D3, D4, D5, D6, D7, D8, D9, D10, D11, D12, D13, D14, D15, D16, D17, D18, D19, D20, D21, D22, D29: GREEN-LED; LED_1206_3216Metric_Castellated
D23, D24, D25, D26, D27, D28, D30: LED; LED_1206_3216Metric_Castellated
D31: D_Schottky; D_SMA_Handsoldering
D32, D33: 1N47xxA; D_DO-41_SOD81_P10.16mm_Horizontal
F1: Fuse; Fuse_2920_7451Metric_Castellated
J1, J11: Screw_Terminal_01x02; Altech_AK300_1x02_P5.00mm_45-Degree
J2, J7, J8: Screw_Terminal_01x06; Altech_AK300_1x06_P5.00mm_45-Degree
J3: Screw_Terminal_01x10; Altech_AK300_1x10_P5.00mm_45-Degree
J4, J5: Screw_Terminal_01x05; Altech_AK300_1x05_P5.00mm_45-Degree
J6: RJ45_LED; RJ45_Hanrun_HR911105A
J9: DD2712SA - 5V; PinSocket_1x06_P2.54mm_Vertical
J10: DD2712SA - 12V; PinSocket_1x06_P2.54mm_Vertical
J12: Ethernet; PinHeader_1x06_P2.54mm_Vertical
J13: Screw_Terminal_01x04; Altech_AK300_1x04_P5.00mm_45-Degree
J14: CAN; PinHeader_1x04_P2.54mm_Vertical
J15: SERIAL_1; PinHeader_1x04_P2.54mm_Vertical
J16: I2C0; PinHeader_1x04_P2.54mm_Vertical
J17: I2C1; PinHeader_1x04_P2.54mm_Vertical
J18, J20, J21, J22, J23, J24, J25: Screw_Terminal_01x01; PinHeader_1x01_P2.54mm_Vertical
J19: SERIAL_5; PinHeader_1x04_P2.54mm_Vertical
J26: 3V3; PinHeader_1x01_P2.54mm_Vertical
J27: 5V; PinHeader_1x01_P2.54mm_Vertical
K1, K2, K3, K4, K5, K6, K7, K8: UMS05-1A80-75L; Relay_SPST_TE_PCN-1xxD3MHZ
L1: 0.1uH; L_0805_2012Metric_Pad1.15x1.40mm_HandSolder
Q1, Q2, Q3, Q4, Q5, Q6, Q7: IRG4PF50W; TO-252-2
R1, R2, R3, R4, R5, R6, R7, R8, R9, R10, R11, R12, R13, R14, R81: 20k; R_1206_3216Metric_Pad1.30x1.75mm_HandSolder
R15, R16, R17, R18, R19, R20, R21, R22, R23, R24, R25, R26, R27, R28, R41, R42, R43, R82: 10K; R_0603_1608Metric
R29, R30: 10k; R_0603_1608Metric
R31, R50: 1.2k; R_1206_3216Metric_Pad1.30x1.75mm_HandSolder
R32, R33, R34, R35, R36, R37, R38, R39: 4.7k; R_1206_3216Metric_Pad1.30x1.75mm_HandSolder
R40: 2.7k; R_0603_1608Metric
R44, R45: 470; R_0603_1608Metric
R46, R47, R48, R49: 49.9; R_0805_2012Metric_Pad1.20x1.40mm_HandSolder
R51, R56, R57, R58, R59, R60, R83: 1k; R_0603_1608Metric
R52, R61, R62, R63, R64, R65, R84: 390; R_0603_1608Metric_Pad0.98x0.95mm_HandSolder
R53, R54, R66, R67, R69, R70, R72, R73, R75, R76, R78, R79, R85, R86: 1k; R_0805_2012Metric_Pad1.20x1.40mm_HandSolder
R55, R68, R71, R74, R77, R80, R87: 10k; R_0805_2012Metric_Pad1.20x1.40mm_HandSolder
R88, R89, R91, R92: 10k; R_1206_3216Metric
SW1, SW2, SW3, SW5: SW_DIP_x01; PinHeader_1x02_P2.54mm_Vertical
SW4: Prog; PinHeader_1x02_P2.54mm_Vertical
SW6: SW_DIP_x01; SW_DIP_SPSTx01_Slide_9.78x4.72mm_W7.62mm_P2.54mm
U1, U2, U3, U4, U5, U6, U7, U8, U11, U12, U13, U14, U34: tlp127; MFSOP6-4_4.4x3.6mm_P1.27mm
U9, U10, U28, U29, U30, U31, U32, U33, U35: TLP127; MFSOP6-4_4.4x3.6mm_P1.27mm
U15, U16: 74HC14
U17: 74HC14; SOIC-14_3.9x8.7mm_P1.27mm
U18, U20: 74HC245; SO-20_12.8x7.5mm_P1.27mm
U19: Teensy3.5_All_Pins; Teensy35_36_MODIFY
U21: ULN2803A; SOP-18_7x12.5mm_P1.27mm
U22, U23, U26, U27: 74AHCT125; SOIC-14_3.9x8.7mm_P1.27mm
U24: ENC28J60x-SS; SSOP-28_5.3x10.2mm_P0.65mm
U25: LD1117S33TR_SOT223; SOT-223-3_TabPin2
U36: LM7810_TO220; TO-220-3_Vertical
Y1: 25Mhz; Crystal_HC49-4H_Vertical

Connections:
1C: D15.1 (K), K1.1, U21.11 (O8)
1M: D1.1 (K), D2.1 (K), D3.1 (K), D4.1 (K), D5.1 (K), D6.1 (K), D7.1 (K), D8.1 (K), D9.1 (K), D10.1 (K), D11.1 (K), D12.1 (K), D13.1 (K), D14.1 (K), D29.1 (K), J3.1
1Y: U21.1 (I1), U23.3 (1Y)
1Y1: R51.1, R52.2, U26.3 (1Y)
2C: D16.1 (K), K2.1, U21.12 (O7)
2Y: U21.2 (I2), U23.6 (2Y)
2Y1: R60.1, R65.2, U26.6 (2Y)
3.3V: C16.1, C21.1, C22.1, J12.2, J14.2, J26.1, L1.1, R41.2, R42.2, R43.2, U24.15 (VDDTX), U24.19 (VDDRX), U24.20 (VDDPLL), U24.25 (VDDOSC), U24.28 (VDD), U25.2 (VO)
3C: D17.1 (K), K3.1, U21.13 (O6)
3Y: U21.3 (I3), U23.8 (3Y)
3Y1: R59.1, R64.2, U26.8 (3Y)
4C: D18.1 (K), K4.1, U21.14 (O5)
4Y: U21.4 (I4), U23.11 (4Y)
4Y1: R58.1, R63.2, U26.11 (4Y)
5C: D19.1 (K), K5.1, U21.15 (O4)
5V: J9.1, J9.2, J15.2, J16.2, J17.2, J19.2, J27.1, R15.2, R16.2, R17.2, R18.2, R19.2, R20.2, R21.2, R22.2, R23.2, R24.2, R25.2, R26.2, R27.2, R28.2, R29.2, R30.2, R31.2, R50.2, R82.2, SW4.2, U15.14 (VCC), U16.14 (VCC), U17.14 (VCC), U18.1 (A->B), U18.20 (VCC), U20.1 (A->B), U20.20 (VCC), U22.14 (VCC), U23.14 (VCC), U25.3 (VI), U26.14 (VCC), U27.14 (VCC)
5Y: U21.5 (I5), U22.3 (1Y)
5Y1: R83.1, R84.2, U27.3 (1Y)
6C: D20.1 (K), K6.1, U21.16 (O3)
6Y: U21.6 (I6), U22.6 (2Y)
7C: D21.1 (K), K7.1, U21.17 (O2)
7Y: U21.7 (I7), U22.11 (4Y)
7Y1: R57.1, R62.2, U27.8 (3Y)
8C: D22.1 (K), K8.1, U21.18 (O1)
8Y: U21.8 (I8), U22.8 (3Y)
8Y1: R56.1, R61.2, U27.11 (4Y)
10V: C26.1, C27.1, J13.3, U36.3 (VO)
12V: J10.1, J10.2, J11.2
24V: D31.2 (A), F1.2, J9.5, J9.6, J10.5, J10.6, K1.2, K2.2, K3.2, K4.2, K5.2, K6.2, K7.2, K8.2, R32.2, R33.2, R34.2, R35.2, R36.2, R37.2, R38.2, R39.2, U21.10 (COM)
A1: J13.2, R88.2
A2: J13.1, R89.2
A21: J21.1, U19.37 (A21_DAC0)
A22: J22.1, U19.38 (A22_DAC1)
AA0: U17.6, U20.8 (A6)
AA1: U17.4, U20.7 (A5)
AA2: U17.2, U20.6 (A4)
AA3: U16.6, U20.5 (A3)
AA4: U16.8, U20.4 (A2)
AA5: U16.10, U20.3 (A1)
AA6: U16.12, U20.2 (A0)
AA7: U16.4, U18.9 (A7)
AA8: U16.2, U18.8 (A6)
AA9: U15.6, U18.7 (A5)
AA10: U15.8, U18.6 (A4)
AA11: U15.4, U18.5 (A3)
AA12: U15.2, U18.4 (A2)
AA13: U15.10, U18.3 (A1)
AA14: U15.12, U18.2 (A0)
AN2: D33.1 (K), R89.1, R92.2, U19.43 (16_A2_SCL0_Touch)
AN3: D32.1 (K), R88.1, R91.2, U19.44 (17_A3_SDA0_Touch)
CAN0Rx: J14.3, U19.6 (4_PWM_CAN0RX_SDA2)
CAN0Tx: J14.4, U19.5 (3_PWM_CAN0TX_SCL2)
COM0: J5.5, K1.4, K2.4, K3.4, K4.4
COM1: J4.5, K5.4, K6.4, K7.4, K8.4
COM2: J7.5, Q1.3 (E), Q2.3 (E), Q3.3 (E), Q4.3 (E), R55.2, R74.2, R77.2, R80.2
COM3: J8.3, Q5.3 (E), Q6.3 (E), R68.2, R71.2
COM4: J8.5, Q7.3 (E), R87.2
CS: J12.3, R41.1, U19.12 (10_PWM_TX2_CS0), U24.9 (~CS)
D2: U18.18 (B0), U19.4 (2_PWM)
D5: U18.17 (B1), U19.7 (5_PWM_TX1_MISO1)
D6: U18.16 (B2), U19.8 (6_PWM)
D7: U18.15 (B3), U19.9 (7_RX3_MOSI0_SCL0)
D8: U18.14 (B4), U19.10 (8_TX3_MISO0_SDA0)
D9: U18.13 (B5), U19.11 (9_PWM_RX2_CS0)
D14: U19.41 (14_A0_PWM_SCK0), U26.2 (1A)
D15: U19.42 (15_A1_CS0_Touch), U23.9 (3A)
D20: U19.47 (20_A6_PWM_CS0_SCK1), U26.12 (4A)
D21: U19.48 (21_A7_PWM_CS0_MOSI1), U27.9 (3A)
D22: U19.49 (22_A8_PWM_Touch), U27.12 (4A)
D23: U19.50 (23_A9_PWM_Touch), U27.2 (1A)
D24: U18.12 (B6), U19.16 (24)
D25: U18.11 (B7), U19.17 (25)
D26: U19.18 (26_TX1_SCL2), U20.18 (B0)
D27: U19.19 (27_RX1_SCK0), U20.17 (B1)
D28: U19.20 (28_MOSI0), U20.16 (B2)
D29: U19.21 (29_PWM_CAN0TX_Touch), U20.15 (B3)
D30: U19.22 (30_PWM_CAN0RX_Touch), U20.14 (B4)
D31: U19.23 (31_A12_RX4_CS1), U20.13 (B5)
D32: U19.24 (32_A13_TX4_SCK1), U20.12 (B6)
D35: U19.32 (35_A16_PWM), U26.9 (3A)
D36: U19.33 (36_A17_PWM), U26.5 (2A)
D39: U19.36 (39_A20), U23.12 (4A)
D43: J18.1, U19.70 (43_CS2)
D44: U19.71 (44_MOSI2), U22.12 (4A)
D45: U19.72 (45_MISO2), U22.9 (3A)
D46: U19.73 (46_SCK2), U22.5 (2A)
D47: J20.1, U19.76 (47_RX6_SCL0)
D48: U19.77 (48_TX6_SDA0), U22.2 (1A)
D49: U19.78 (49_A23), U23.5 (2A)
D50: U19.79 (50_A24), U23.2 (1A)
D55: J24.1, U19.84 (55)
D56: J23.1, U19.85 (56)
D57: J25.1, U19.86 (57)
GND: BT1.2 (-), C1.2, C2.2, C3.2, C4.2, C5.2, C6.2, C7.2, C8.2, C9.2, C10.2, C11.2, C12.2, C13.2, C14.2, C15.2, C16.2, C17.2, C18.2, C19.2, C20.2, C21.2, C22.2, C23.2, C24.2, C25.2, C26.2, C27.2, D23.1 (K), D24.1 (K), D25.1 (K), D26.1 (K), D27.1 (K), D28.1 (K), D30.1 (K), D32.2 (A), D33.2 (A), J1.1, J6.10, J6.11, J9.3, J9.4, J10.3, J10.4, J11.1, J12.1, J13.4, J14.1, J15.1, J16.1, J17.1, J19.1, R40.1, R91.1, R92.1, SW1.1, SW2.1, SW3.1, SW5.1, U1.4, U2.4, U3.4, U4.4, U5.4, U6.4, U7.4, U8.4, U9.4, U10.4, U11.4, U12.4, U13.4, U14.4, U15.7 (GND), U16.7 (GND), U17.7 (GND), U18.10 (GND), U19.1 (GND), U19.27 (GND), U19.39 (GND), U19.61 (GND), U19.62 (GND), U19.74 (GND), U20.10 (GND), U21.9 (GND), U22.7 (GND), U23.7 (GND), U24.2 (VSS), U24.11 (VSSRX), U24.18 (VSSTX), U24.21 (VSSPLL), U24.22 (VSSOSC), U25.1 (GND), U26.7 (GND), U27.7 (GND), U28.3, U29.3, U30.3, U31.3, U32.3, U33.3, U34.4, U35.3, U36.2 (GND)
IN0: J3.2, R81.2
IN1: J3.3, R14.2
IN2: J3.4, R13.2
IN3: J3.5, R12.2
IN4: J3.6, R11.2
IN5: J3.7, R10.2
IN6: J3.8, R9.2
IN7: J3.9, R8.2
IN8: J3.10, R7.2
IN9: J2.1, R6.2
IN10: J2.2, R5.2
IN11: J2.3, R4.2
IN12: J2.4, R3.2
IN13: J2.5, R2.2
IN14: J2.6, R1.2
INT: R42.1, U24.4 (~INT)
LEDA: R44.2, U24.27 (LEDA)
LEDB: R45.1, U24.26 (LEDB)
MISO: J12.5, U19.14 (12_MISO0), U24.6 (SO)
MOSI: J12.4, U19.13 (11_MOSI0), U24.7 (SI)
unnamed: C1.1, R15.1, U1.6, U15.13
unnamed: C2.1, R16.1, U2.6, U15.11
unnamed: C3.1, R17.1, U3.6, U15.1
unnamed: C4.1, R18.1, U4.6, U15.3
unnamed: C5.1, R19.1, U5.6, U15.9
unnamed: C6.1, R20.1, U6.6, U15.5
unnamed: C7.1, R21.1, U7.6, U16.1
unnamed: C8.1, R22.1, U8.6, U16.3
unnamed: C9.1, R23.1, U9.6, U16.13
unnamed: C10.1, R24.1, U10.6, U16.11
unnamed: C11.1, R25.1, U11.6, U16.9
unnamed: C12.1, R26.1, U12.6, U16.5
unnamed: C13.1, R27.1, U13.6, U17.1
unnamed: C14.1, R28.1, U14.6, U17.3
unnamed: C15.1, U24.1 (VCAP)
unnamed: C19.1, R47.2, R49.2
unnamed: C23.1, R82.1, U17.5, U34.6
unnamed: C24.1, C25.1, D31.1 (K), U36.1 (VI)
unnamed: D1.2 (A), U1.3
unnamed: D2.2 (A), U2.3
unnamed: D3.2 (A), U3.3
unnamed: D4.2 (A), U4.3
unnamed: D5.2 (A), U5.3
unnamed: D6.2 (A), U6.3
unnamed: D7.2 (A), U7.3
unnamed: D8.2 (A), U8.3
unnamed: D9.2 (A), U9.3
unnamed: D10.2 (A), U10.3
unnamed: D11.2 (A), U11.3
unnamed: D12.2 (A), U12.3
unnamed: D13.2 (A), U13.3
unnamed: D14.2 (A), U14.3
unnamed: D15.2 (A), R32.1
unnamed: D16.2 (A), R33.1
unnamed: D17.2 (A), R34.1
unnamed: D18.2 (A), R35.1
unnamed: D19.2 (A), R36.1
unnamed: D20.2 (A), R37.1
unnamed: D21.2 (A), R38.1
unnamed: D22.2 (A), R39.1
unnamed: D23.2 (A), R51.2
unnamed: D24.2 (A), R56.2
unnamed: D25.2 (A), R57.2
unnamed: D26.2 (A), R58.2
unnamed: D27.2 (A), R59.2
unnamed: D28.2 (A), R60.2
unnamed: D29.2 (A), U34.3
unnamed: D30.2 (A), R83.2
unnamed: F1.1, SW6.2
unnamed: J1.2, SW6.1
unnamed: J6.9, R44.1
unnamed: J6.12, R45.2
unnamed: Q1.1 (G), R54.1
unnamed: Q2.1 (G), R79.1
unnamed: Q3.1 (G), R76.1
unnamed: Q4.1 (G), R73.1
unnamed: Q5.1 (G), R70.1
unnamed: Q6.1 (G), R67.1
unnamed: Q7.1 (G), R86.1
unnamed: R1.1, U1.1
unnamed: R2.1, U2.1
unnamed: R3.1, U3.1
unnamed: R4.1, U4.1
unnamed: R5.1, U5.1
unnamed: R6.1, U6.1
unnamed: R7.1, U7.1
unnamed: R8.1, U8.1
unnamed: R9.1, U9.1
unnamed: R10.1, U10.1
unnamed: R11.1, U11.1
unnamed: R12.1, U12.1
unnamed: R13.1, U13.1
unnamed: R14.1, U14.1
unnamed: R29.1, SW1.2, U18.19 (CE)
unnamed: R30.1, SW2.2, U20.19 (CE)
unnamed: R40.2, U24.14 (RBIAS)
unnamed: R52.1, U28.1
unnamed: R53.2, U28.6
unnamed: R54.2, R55.1, U28.4
unnamed: R61.1, U29.1
unnamed: R62.1, U30.1
unnamed: R63.1, U31.1
unnamed: R64.1, U32.1
unnamed: R65.1, U33.1
unnamed: R66.2, U29.6
unnamed: R67.2, R68.1, U29.4
unnamed: R69.2, U30.6
unnamed: R70.2, R71.1, U30.4
unnamed: R72.2, U31.6
unnamed: R73.2, R74.1, U31.4
unnamed: R75.2, U32.6
unnamed: R76.2, R77.1, U32.4
unnamed: R78.2, U33.6
unnamed: R79.2, R80.1, U33.4
unnamed: R81.1, U34.1
unnamed: R84.1, U35.1
unnamed: R85.2, U35.6
unnamed: R86.2, R87.1, U35.4
O0: J5.4, K1.3
O1: J5.3, K2.3
O2: J5.2, K3.3
O3: J5.1, K4.3
O4: J4.4, K5.3
O5: J4.3, K6.3
O6: J4.2, K7.3
O7: J4.1, K8.3
O8: J7.1, Q1.2 (C)
O9: J7.2, Q2.2 (C)
O10: J7.3, Q3.2 (C)
O11: J7.4, Q4.2 (C)
O12: J8.1, Q5.2 (C)
O13: J8.2, Q6.2 (C)
O14: J8.4, Q7.2 (C)
OE: R31.1, SW3.2, U22.1 (1OE), U22.4 (2OE), U22.10 (3OE), U22.13 (4OE), U23.1 (1OE), U23.4 (2OE), U23.10 (3OE), U23.13 (4OE)
OE1: R50.1, SW5.2, U26.1 (1OE), U26.4 (2OE), U26.10 (3OE), U26.13 (4OE), U27.1 (1OE), U27.4 (2OE), U27.10 (3OE), U27.13 (4OE)
OSC1: C17.1, U24.23 (OSC1), Y1.1
OSC2: C18.1, U24.24 (OSC2), Y1.2
P4: C20.1, J6.4, L1.2, R46.1, R48.1
RD+: J6.3, R47.1, U24.13 (TPIN+)
RD-: J6.6, R49.1, U24.12 (TPIN-)
RST: R43.1, U24.10 (~RESET)
RX1: J15.4, U19.2 (0_RX1_MOSI1_Touch)
RX5: J19.4, U19.31 (34_A15_RX5_CAN1RX_SDA0)
SCK: J12.6, U19.40 (13_SCK0_LED), U24.8 (SCK)
SCL0: J16.4, U19.46 (19_A5_SCL0_Touch)
SCL1: J17.4, U19.34 (37_A18_PWM_SCL1)
SDA0: J16.3, U19.45 (18_A4_SDA0_Touch)
SDA1: J17.3, U19.35 (38_A19_PWM_SDA1)
TD+: J6.1, R46.2, U24.17 (TPOUT+)
TD-: J6.2, R48.2, U24.16 (TPOUT-)
TX1: J15.3, U19.3 (1_TX1_MISO1_Touch)
TX5: J19.3, U19.30 (33_A14_TX5_CAN1TX_SCL0)
VBAT: BT1.1 (+), U19.25 (VBat)
Vge: J7.6, R53.1, R72.1, R75.1, R78.1
Vge1: J8.6, R66.1, R69.1, R85.1
Vin: SW4.1, U19.53 (Vin)

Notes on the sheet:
Los ánodos de los leds son los pines 9 y 12, la imagen del led está mal en el componente
MODBUS COM
DIGITALS INPUTS
DIGITALS OUTPUTS
PWM OUTPUTS
POWER SUPPLY
ANALOG INPUTS
Comunication
Nota: A VGE y VGE1 se conectan los 12Vdc que entrega el regulador de voltage DD2712SA -12V

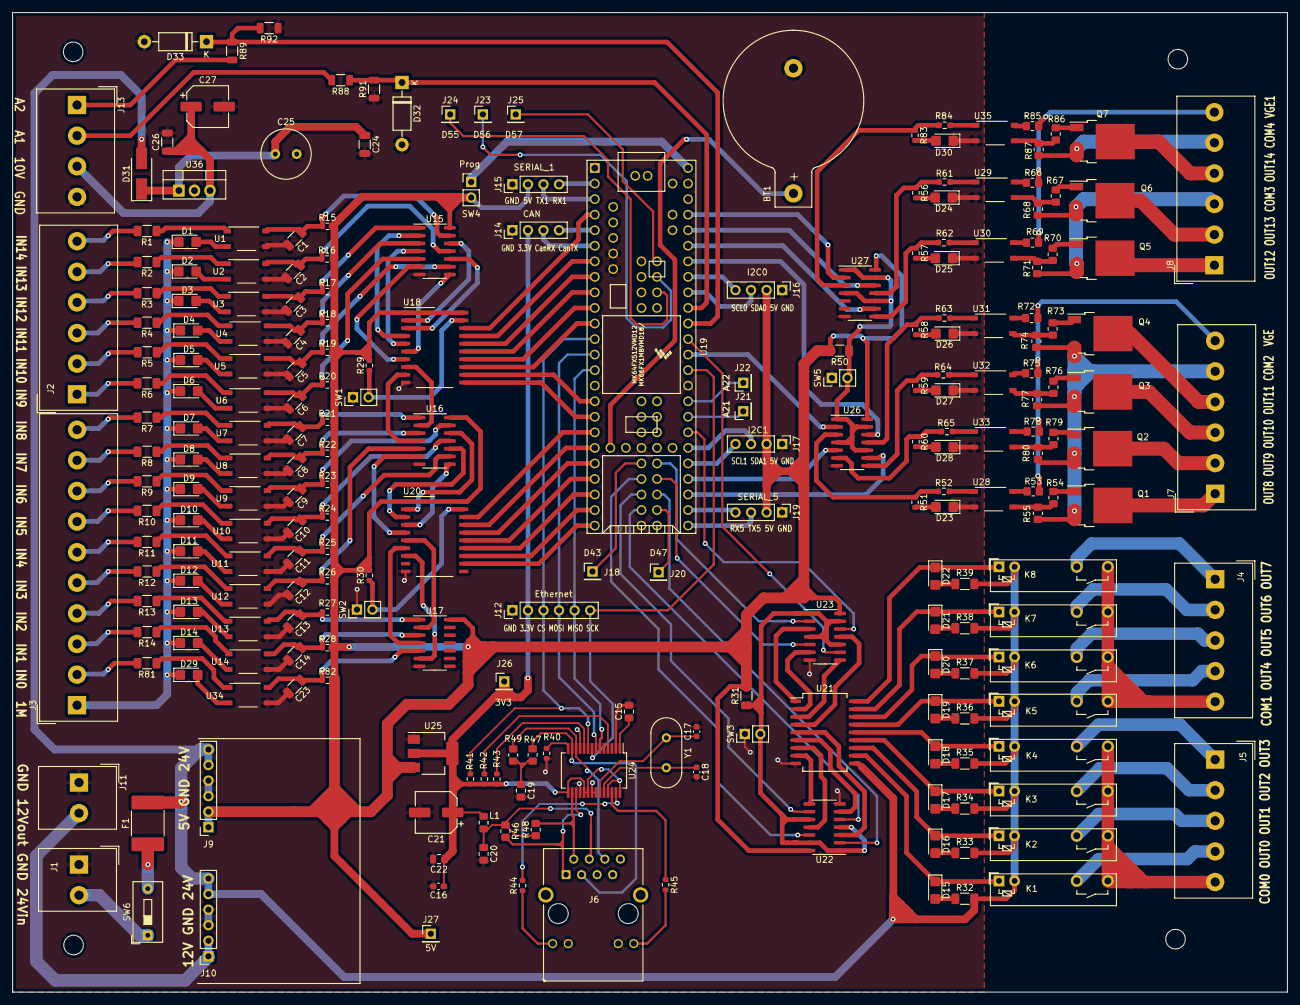
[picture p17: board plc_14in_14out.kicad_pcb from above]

Board: 2 copper layers, 208.3 x 160.0 mm, 239 parts (0 on the bottom side), 250 nets.

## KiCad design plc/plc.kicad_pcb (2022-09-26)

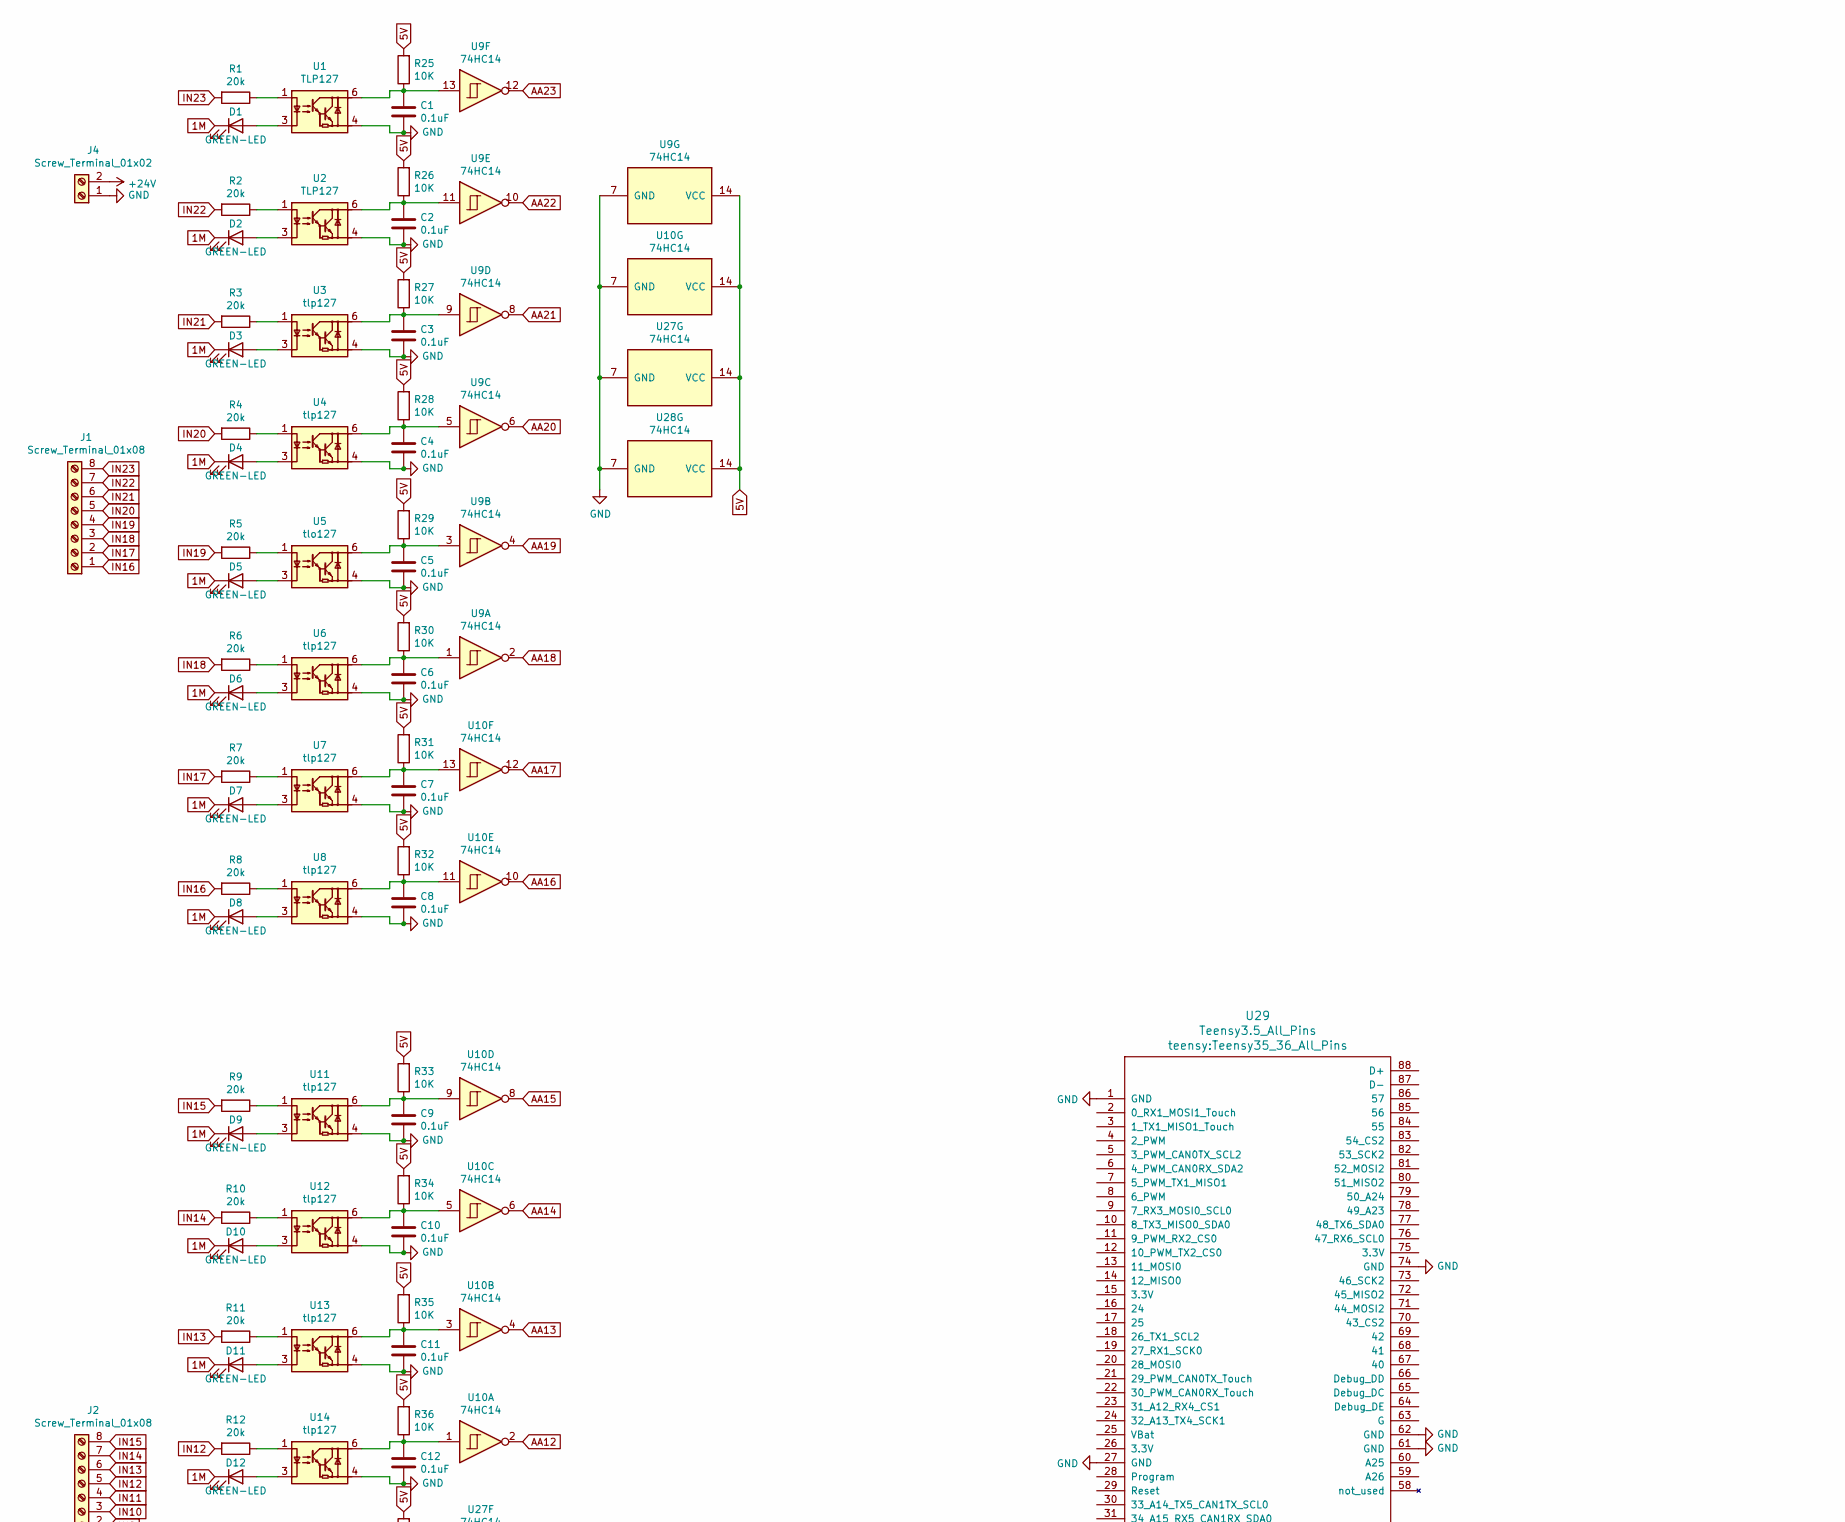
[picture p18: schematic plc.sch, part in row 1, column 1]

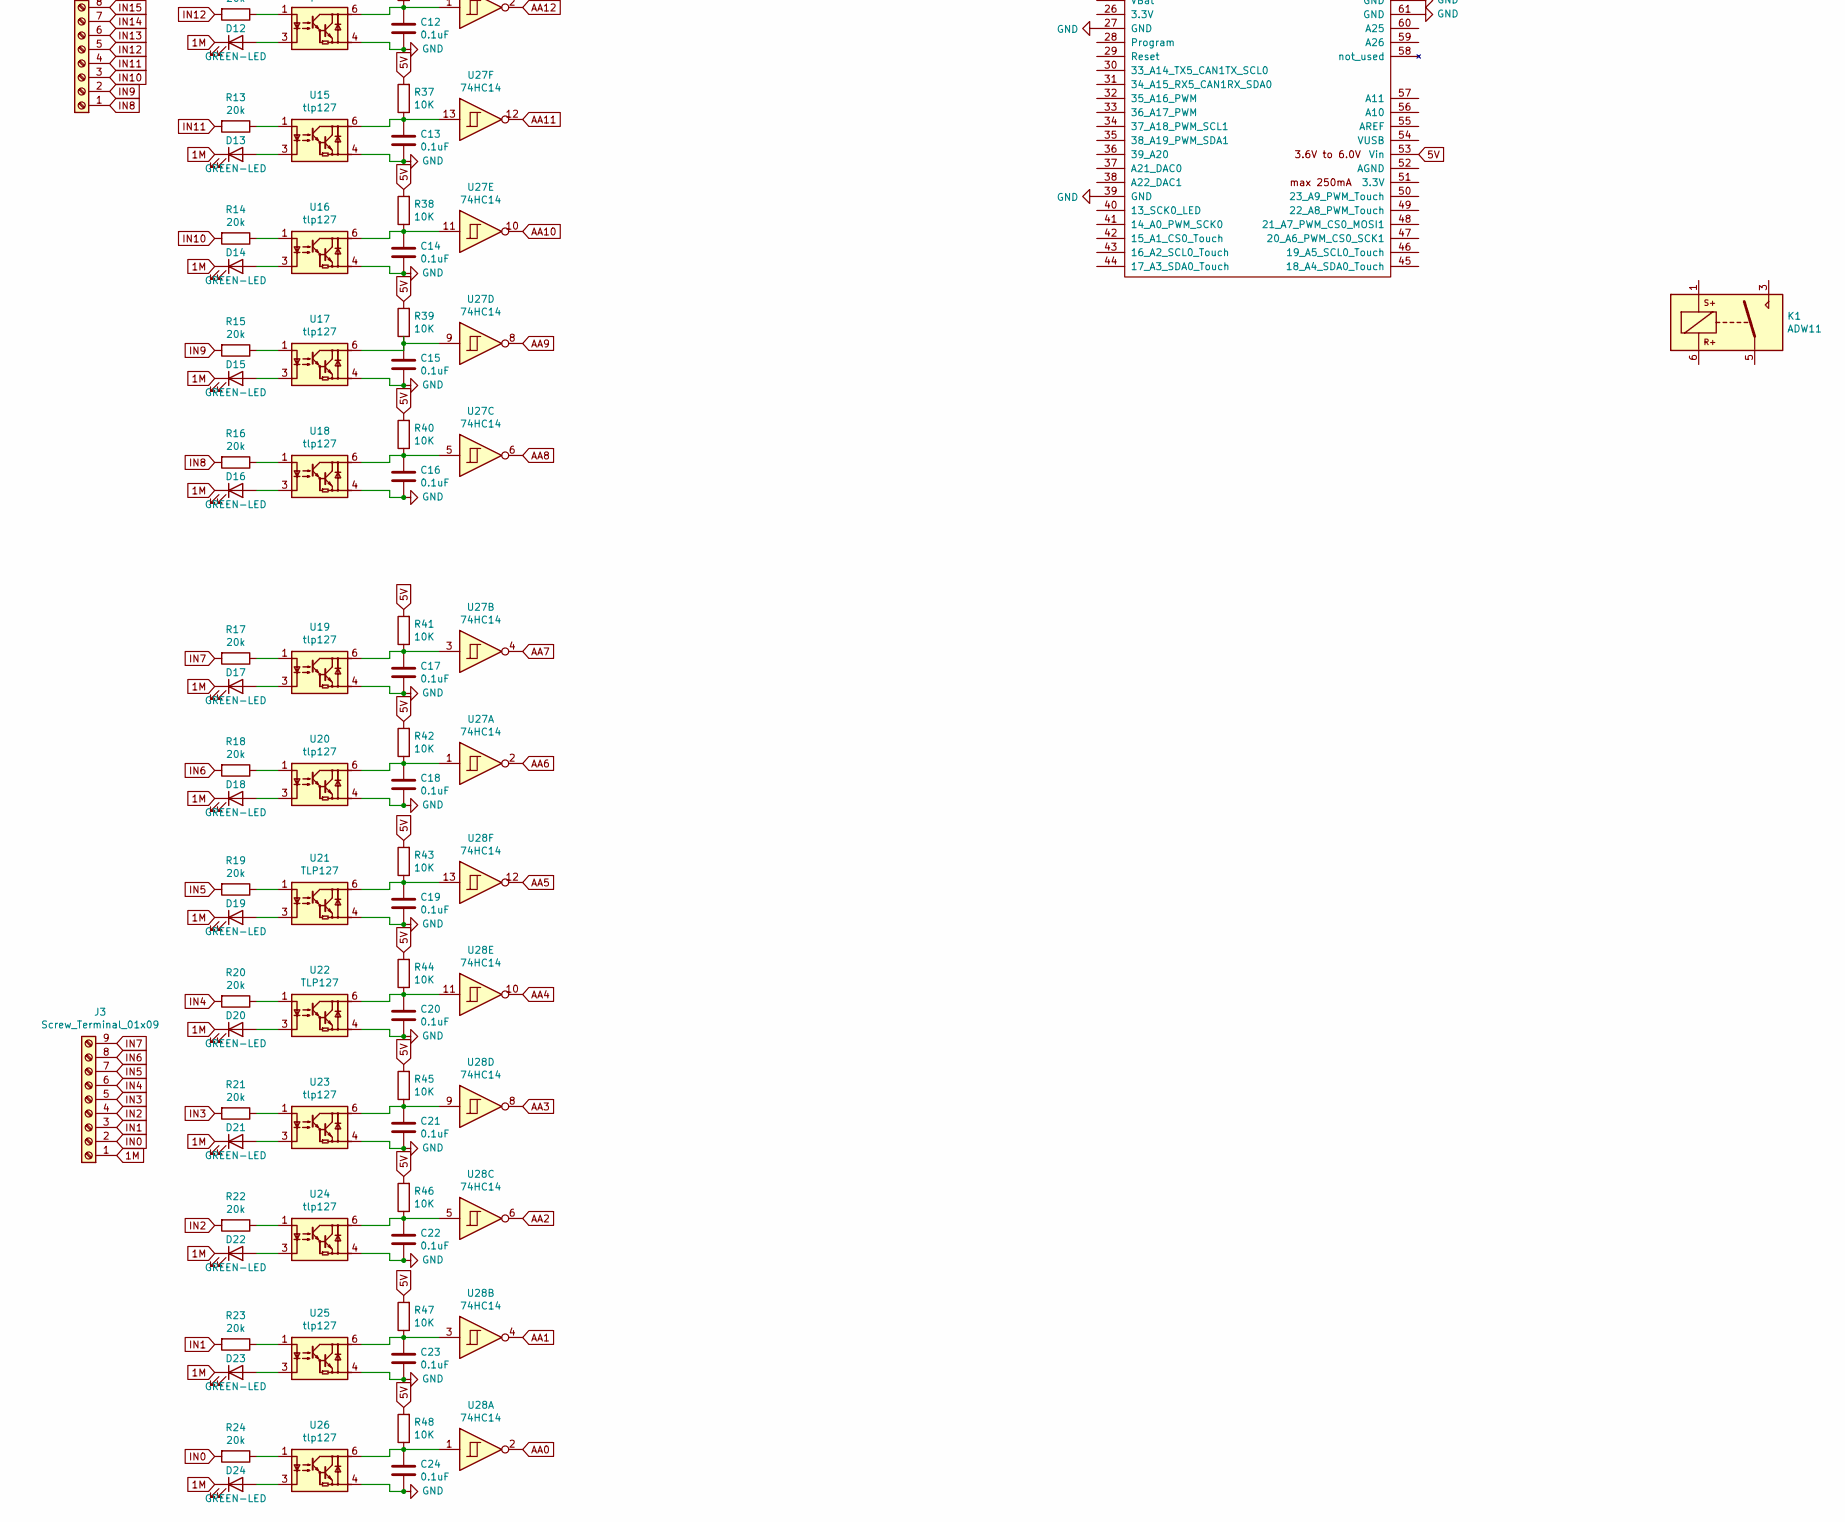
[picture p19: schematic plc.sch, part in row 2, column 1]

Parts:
C1, C2, C3, C4, C5, C6, C7, C8, C9, C10, C11, C12, C13, C14, C15, C16, C17, C18, C19, C20, C21, C22, C23, C24: 0.1uF; C_1206_3216Metric
D1, D2, D3, D4, D5, D6, D7, D8, D9, D10, D11, D12, D13, D14, D15, D16, D17, D18, D19, D20, D21, D22, D23, D24: GREEN-LED; LED_1206_3216Metric_Castellated
J1, J2: Screw_Terminal_01x08; Altech_AK300_1x08_P5.00mm_45-Degree
J3: Screw_Terminal_01x09; Altech_AK300_1x09_P5.00mm_45-Degree
J4: Screw_Terminal_01x02; Altech_AK300_1x02_P5.00mm_45-Degree
K1: ADW11; Relay_1P1T_NO_10x24x18.8mm_Panasonic_ADW11xxxxW_THT
R1, R2, R3, R4, R5, R6, R7, R8, R9, R10, R11, R12, R13, R14, R15, R16, R17, R18, R19, R20, R21, R22, R23, R24: 20k; R_1206_3216Metric_Pad1.30x1.75mm_HandSolder
R25, R26, R27, R28, R29, R30, R31, R32, R33, R34, R35, R36, R37, R38, R39, R40, R41, R42, R43, R44, R45, R46, R47, R48: 10K; R_0603_1608Metric
U1, U2, U21, U22: TLP127; MFSOP6-4_4.4x3.6mm_P1.27mm
U3, U4, U6, U7, U8, U11, U12, U13, U14, U15, U16, U17, U18, U19, U20, U23, U24, U25, U26: tlp127; MFSOP6-4_4.4x3.6mm_P1.27mm
U5: tlo127; MFSOP6-4_4.4x3.6mm_P1.27mm
U9, U10, U27, U28: 74HC14; SOIC-14_3.9x8.7mm_P1.27mm
U29: Teensy3.5_All_Pins; Teensy35_36_All_Pins

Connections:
1M: D1.1 (K), D2.1 (K), D3.1 (K), D4.1 (K), D5.1 (K), D6.1 (K), D7.1 (K), D8.1 (K), D9.1 (K), D10.1 (K), D11.1 (K), D12.1 (K), D13.1 (K), D14.1 (K), D15.1 (K), D16.1 (K), D17.1 (K), D18.1 (K), D19.1 (K), D20.1 (K), D21.1 (K), D22.1 (K), D23.1 (K), D24.1 (K), J3.1
5V: R25.2, R26.2, R27.2, R28.2, R29.2, R30.2, R31.2, R32.2, R33.2, R34.2, R35.2, R36.2, R37.2, R38.2, R39.2, R40.2, R41.2, R42.2, R43.2, R44.2, R45.2, R46.2, R47.2, R48.2, U9.14 (VCC), U10.14 (VCC), U27.14 (VCC), U28.14 (VCC), U29.53 (Vin)
+24V: J4.2
AA0: U28.2
AA1: U28.4
AA2: U28.6
AA3: U28.8
AA4: U28.10
AA5: U28.12
AA6: U27.2
AA7: U27.4
AA8: U27.6
AA9: U27.8
AA10: U27.10
AA11: U27.12
AA12: U10.2
AA13: U10.4
AA14: U10.6
AA15: U10.8
AA16: U10.10
AA17: U10.12
AA18: U9.2
AA19: U9.4
AA20: U9.6
AA21: U9.8
AA22: U9.10
AA23: U9.12
GND: C1.2, C2.2, C3.2, C4.2, C5.2, C6.2, C7.2, C8.2, C9.2, C10.2, C11.2, C12.2, C13.2, C14.2, C15.2, C16.2, C17.2, C18.2, C19.2, C20.2, C21.2, C22.2, C23.2, C24.2, J4.1, U1.4, U2.4, U3.4, U4.4, U5.4, U6.4, U7.4, U8.4, U9.7 (GND), U10.7 (GND), U11.4, U12.4, U13.4, U14.4, U15.4, U16.4, U17.4, U18.4, U19.4, U20.4, U21.4, U22.4, U23.4, U24.4, U25.4, U26.4, U27.7 (GND), U28.7 (GND), U29.1 (GND), U29.27 (GND), U29.39 (GND), U29.61 (GND), U29.62 (GND), U29.74 (GND)
IN0: J3.2, R24.2
IN1: J3.3, R23.2
IN2: J3.4, R22.2
IN3: J3.5, R21.2
IN4: J3.6, R20.2
IN5: J3.7, R19.2
IN6: J3.8, R18.2
IN7: J3.9, R17.2
IN8: J2.1, R16.2
IN9: J2.2, R15.2
IN10: J2.3, R14.2
IN11: J2.4, R13.2
IN12: J2.5, R12.2
IN13: J2.6, R11.2
IN14: J2.7, R10.2
IN15: J2.8, R9.2
IN16: J1.1, R8.2
IN17: J1.2, R7.2
IN18: J1.3, R6.2
IN19: J1.4, R5.2
IN20: J1.5, R4.2
IN21: J1.6, R3.2
IN22: J1.7, R2.2
IN23: J1.8, R1.2
unnamed: C1.1, R25.1, U1.6, U9.13
unnamed: C2.1, R26.1, U2.6, U9.11
unnamed: C3.1, R27.1, U3.6, U9.9
unnamed: C4.1, R28.1, U4.6, U9.5
unnamed: C5.1, R29.1, U5.6, U9.3
unnamed: C6.1, R30.1, U6.6, U9.1
unnamed: C7.1, R31.1, U7.6, U10.13
unnamed: C8.1, R32.1, U8.6, U10.11
unnamed: C9.1, R33.1, U10.9, U11.6
unnamed: C10.1, R34.1, U10.5, U12.6
unnamed: C11.1, R35.1, U10.3, U13.6
unnamed: C12.1, R36.1, U10.1, U14.6
unnamed: C13.1, R37.1, U15.6, U27.13
unnamed: C14.1, R38.1, U16.6, U27.11
unnamed: C15.1, R39.1, U17.6, U27.9
unnamed: C16.1, R40.1, U18.6, U27.5
unnamed: C17.1, R41.1, U19.6, U27.3
unnamed: C18.1, R42.1, U20.6, U27.1
unnamed: C19.1, R43.1, U21.6, U28.13
unnamed: C20.1, R44.1, U22.6, U28.11
unnamed: C21.1, R45.1, U23.6, U28.9
unnamed: C22.1, R46.1, U24.6, U28.5
unnamed: C23.1, R47.1, U25.6, U28.3
unnamed: C24.1, R48.1, U26.6, U28.1
unnamed: D1.2 (A), U1.3
unnamed: D2.2 (A), U2.3
unnamed: D3.2 (A), U3.3
unnamed: D4.2 (A), U4.3
unnamed: D5.2 (A), U5.3
unnamed: D6.2 (A), U6.3
unnamed: D7.2 (A), U7.3
unnamed: D8.2 (A), U8.3
unnamed: D9.2 (A), U11.3
unnamed: D10.2 (A), U12.3
unnamed: D11.2 (A), U13.3
unnamed: D12.2 (A), U14.3
unnamed: D13.2 (A), U15.3
unnamed: D14.2 (A), U16.3
unnamed: D15.2 (A), U17.3
unnamed: D16.2 (A), U18.3
unnamed: D17.2 (A), U19.3
unnamed: D18.2 (A), U20.3
unnamed: D19.2 (A), U21.3
unnamed: D20.2 (A), U22.3
unnamed: D21.2 (A), U23.3
unnamed: D22.2 (A), U24.3
unnamed: D23.2 (A), U25.3
unnamed: D24.2 (A), U26.3
unnamed: R1.1, U1.1
unnamed: R2.1, U2.1
unnamed: R3.1, U3.1
unnamed: R4.1, U4.1
unnamed: R5.1, U5.1
unnamed: R6.1, U6.1
unnamed: R7.1, U7.1
unnamed: R8.1, U8.1
unnamed: R9.1, U11.1
unnamed: R10.1, U12.1
unnamed: R11.1, U13.1
unnamed: R12.1, U14.1
unnamed: R13.1, U15.1
unnamed: R14.1, U16.1
unnamed: R15.1, U17.1
unnamed: R16.1, U18.1
unnamed: R17.1, U19.1
unnamed: R18.1, U20.1
unnamed: R19.1, U21.1
unnamed: R20.1, U22.1
unnamed: R21.1, U23.1
unnamed: R22.1, U24.1
unnamed: R23.1, U25.1
unnamed: R24.1, U26.1

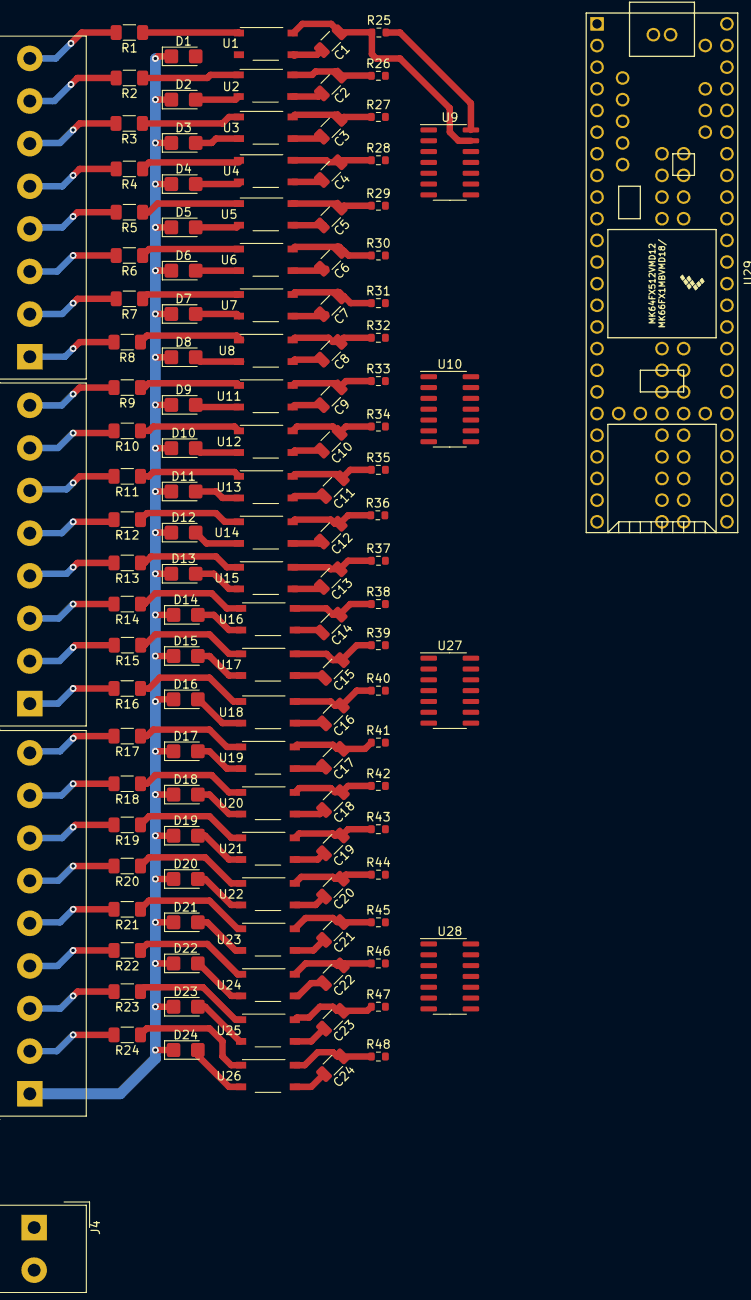
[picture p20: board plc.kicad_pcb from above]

Board: 2 copper layers, 129 parts (0 on the bottom side), 99 nets.

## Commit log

2022-09-26 Initial commit.
    [.100 Header.SLDPRT, Hirose Micro USB Digikey PN H11635CT-ND.SLDASM, Hirose Micro USB Digikey PN H11635CT-ND.SLDPRT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]
2022-09-26 Testing git.
    This new version has a wire unconnected in the schematic.
    [plc_14in_14out.sch]
2022-10-16 Added the PWM output with IGBT, the ethernet port.
    [plc_14in_14out.kicad_pcb, plc_14in_14out.sch]
2022-10-24 Version 1 lista con gerbers
    [plc_14in_14out-B_Cu.gbl, plc_14in_14out-B_Mask.gbs, plc_14in_14out-B_Paste.gbp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]
2022-11-12 Added a 3.3V and 5V pins Also commented the regulator used, and how to wire VGE and VGE1
    [plc_14in_14out-B_Cu.gbl, plc_14in_14out-B_Mask.gbs, plc_14in_14out-B_Paste.gbp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]
2022-11-12 Added the RS232 and RS485 to the BOM
    [plc_14in_14out-B_Cu.gbl, plc_14in_14out-B_Mask.gbs, plc_14in_14out-B_Paste.gbp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]
